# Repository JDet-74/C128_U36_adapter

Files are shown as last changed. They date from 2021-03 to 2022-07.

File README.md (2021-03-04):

# C128_U36_adapter
A new design of the megabit adapter for U36 in the C128
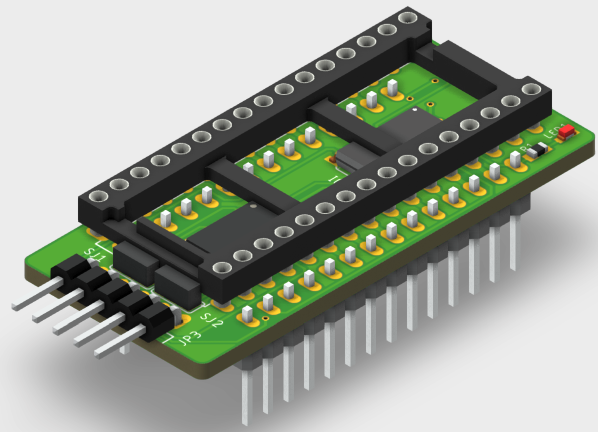
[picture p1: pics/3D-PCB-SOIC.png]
3D PCB SOIC Version
 <br>
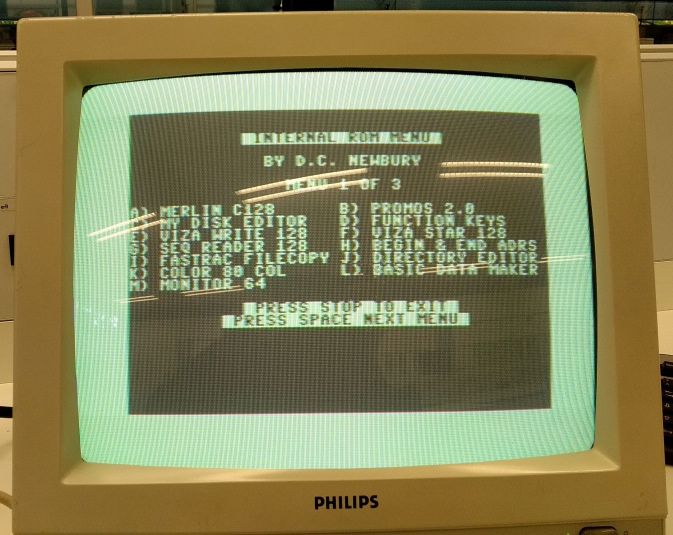
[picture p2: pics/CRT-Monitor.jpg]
CRT Monitor
 <br>

# The story began ...
I tried to recreate the original Megabit adapter for the U36 socket in the C128.
The information to this project I found on cmb8bit.com. You can find the PDFs and the ROM binary file in the <strong>cmb8bit.com</strong> directory.

<ul>
    <li> <a href="./cbm8bit.com/Megabit_internal_rom_manual.pdf"> Megabit internal ROM manual</a> </li>
    <li> <a href="./cbm8bit.com/MegaBit-faq-howtoo.pdf"> Megabit FAQ HowTo</a> </li>
    <li> <a href="./cbm8bit.com/megabit-help.BIN"> megabit-help.bin</a> </li>
</ul>

# The issue was ...
I designed a PCB with the information of the PDFs and tested the soldered PCB. <br>
Unfortunately it does not work :( <br>
Thankfully a guy (Kinzi) from the great Forum64 helped me out by troubleshooting. <br>
I scoped the signals and figured out, that the transistor I used was too slow to trigger the D-FF. <br>
After that I tried logic gates - but this does not work either.
I figured out that there is a GLITCH on Pin12 of U3 <br>
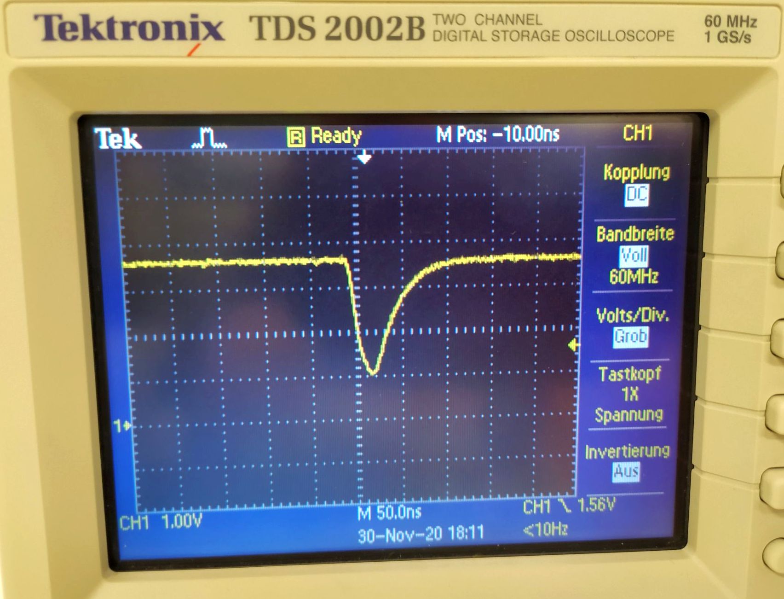
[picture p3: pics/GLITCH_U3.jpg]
GLITCH on U3 pin 12
 <br>
The GLITCH triggered always the D-FF and so it does not work :( what a bummer ;(

# The solution was ...
Kinzi mentioned that the /CS signal from pin12 of U3 has to be synchronized with the 1MHz clock of the C128. <br>
So I poked around with this variation and that was the success. <br>
The solution is to use two 74HCT173 D-FF and one 74HCT14 INV - so the /CS signal from pin 12 of U3 gets synchronized with the system clock
and addresses the ROM. BINGO <br>
<p>Take a look into the <a href="C128_U36_adapter_MANUAL.pdf"> C128 U36 adapter manual</a> or into the 
    <a href="Schematic_U36_adapter.pdf"> SCHEMATIC </a>for further information.</p>

# In the C128D-CR ...
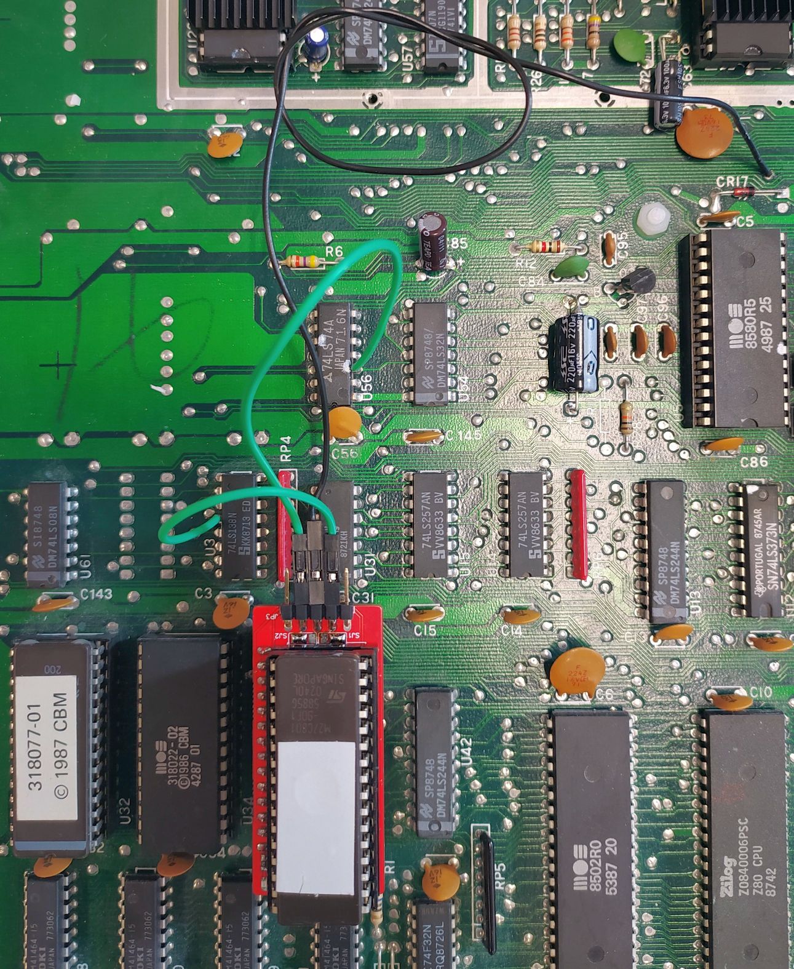
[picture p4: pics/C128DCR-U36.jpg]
C128D-CR with the Megabit ROM
 <br>

# In the C128 ...
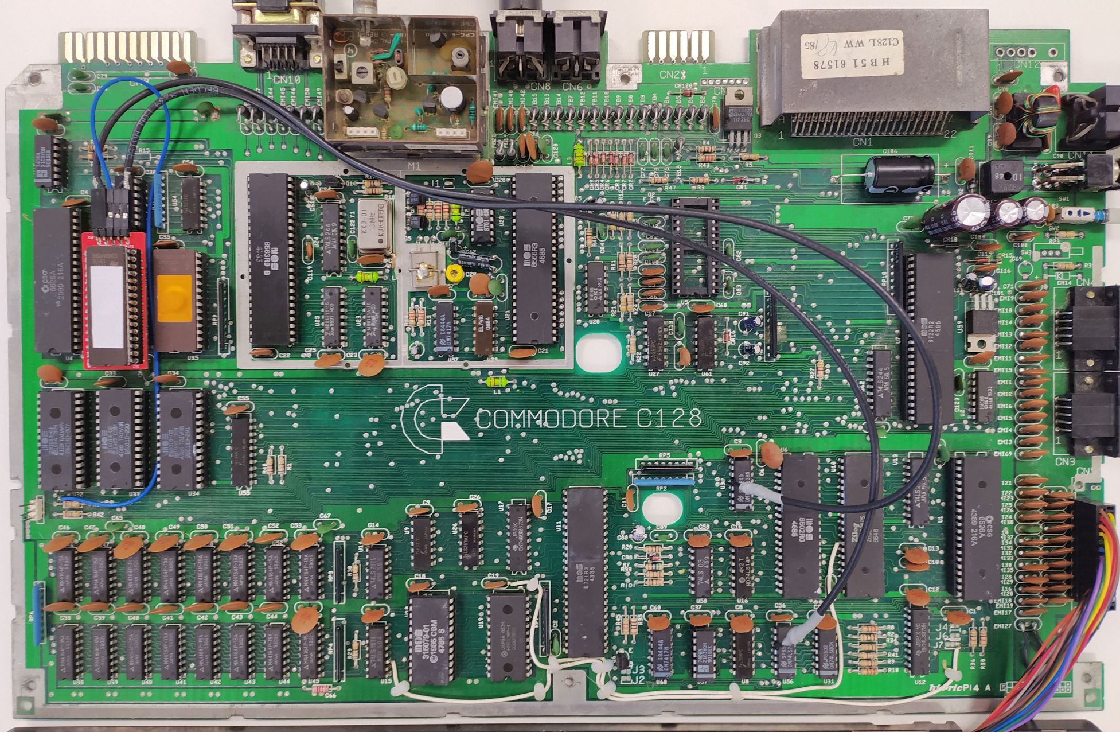
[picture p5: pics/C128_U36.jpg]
C128 with the Megabit ROM
 <br>

# Fabrication files
You can find a panelized GERBER file version and a single file version. <br>
The panelized version should work for the most PCB manufacturer.
I ordered by JLCPCB.

# Contact
For any questions (technical / experience), please use the issue tracking system of github.

Greetz 

JDet

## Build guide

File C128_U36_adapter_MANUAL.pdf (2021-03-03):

# C128_U36_adapter

https://github.com/JDet-74/C128_U36_adapter.git

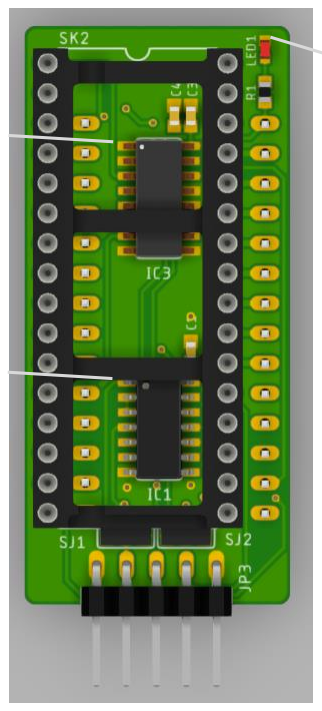
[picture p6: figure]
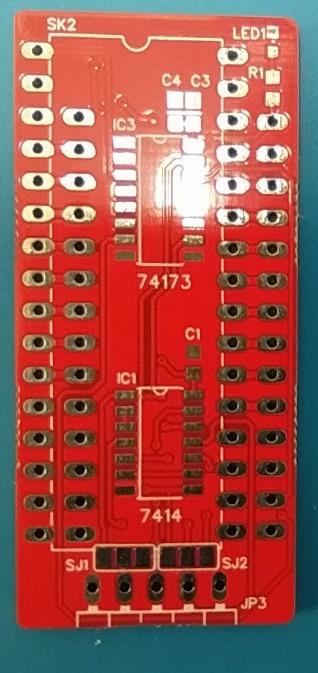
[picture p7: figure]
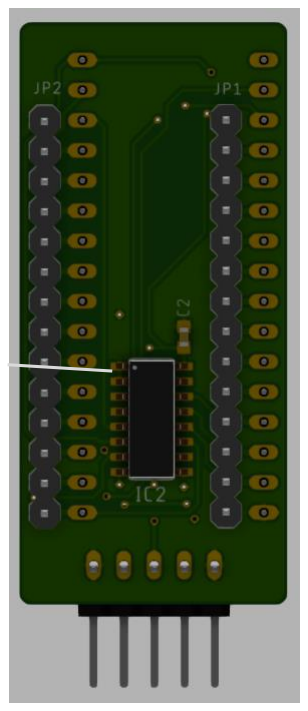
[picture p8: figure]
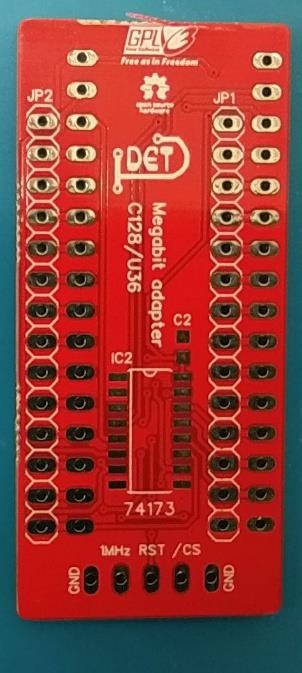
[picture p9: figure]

C128_U36_adapter | Seite: 1 von 3
Bestückungs-Info | Assembling information
TOP Side:

BOTTOM Side:

BOM:

SK2: DIP-32 Socket (2,54 x 15,24mm)
JP1 & JP2: 1x14 pin header (2,54mm) – JP3: 1x5 pin header (2,54mm)
IC1: 74HCT14 (INVERTER) SO14 – IC2 & IC3: 74HCT173 (D-FF) SO14
C1 – C4: 100nF (ceramic capacitor) 0603 – R1: 1,5k (resistor) 0603 – LED1: SMD LED 0603

GND (-)
Kathode / cathode
Pin1

Pin1

Pin1

/CS through 4 inverter gates to the D-FFs

C128D-CR | C128D-CR

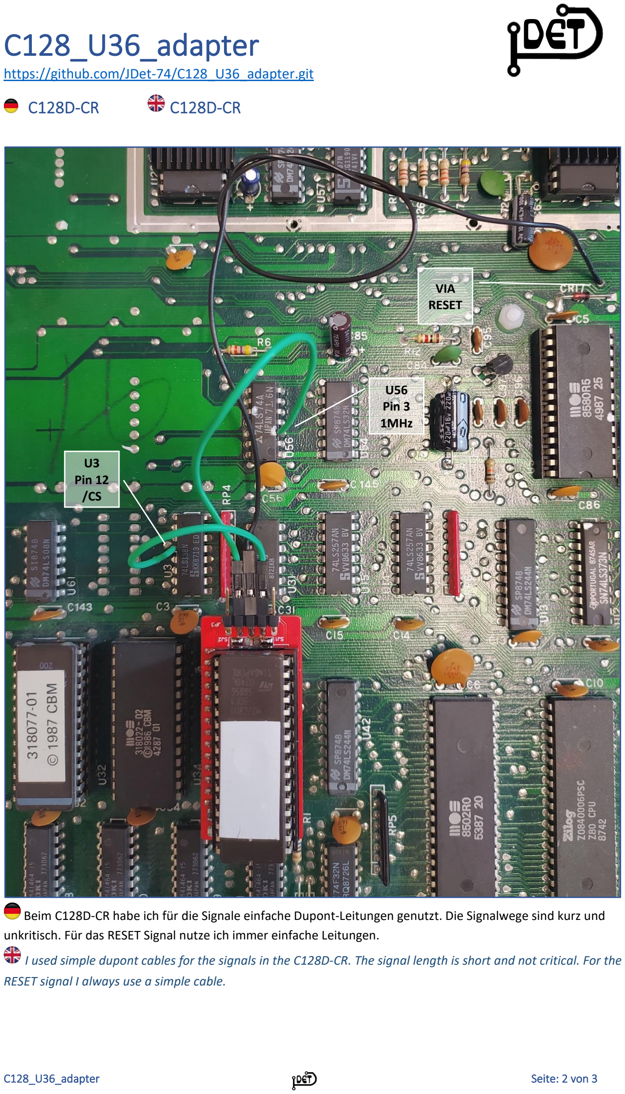
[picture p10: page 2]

https://github.com/JDet-74/C128_U36_adapter.git

Beim C128D-CR habe ich für die Signale einfache Dupont-Leitungen genutzt. Die Signalwege sind kurz und unkritisch. Für das RESET Signal nutze ich immer einfache Leitungen.

I used simple dupont cables for the signals in the C128D-CR. The signal length is short and not critical. For the RESET signal I always use a simple cable.

U3
Pin 12
/CS

U56
Pin 3
1MHz

VIA
RESET https://github.com/JDet-74/C128_U36_adapter.git
C128 | C128

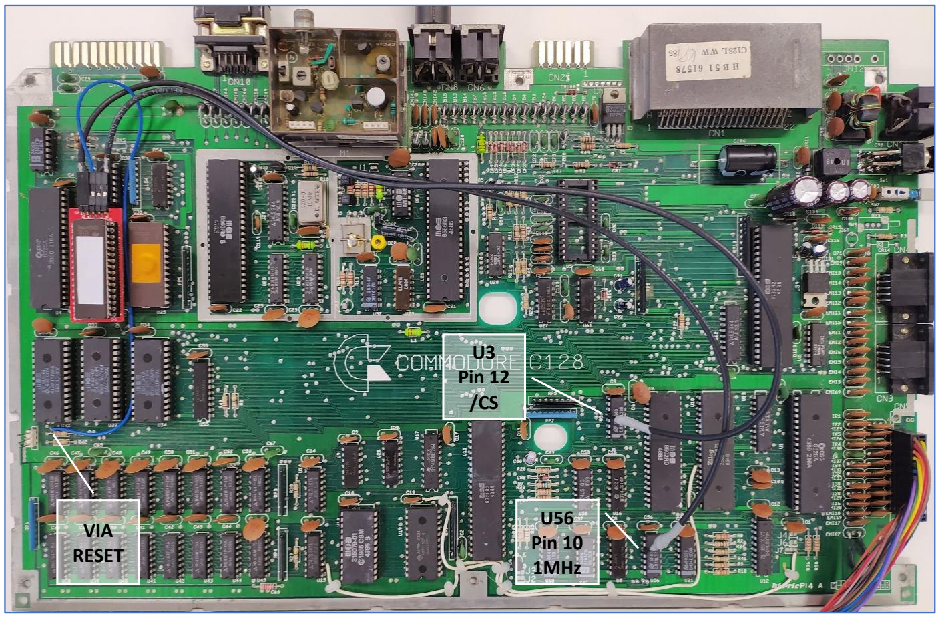
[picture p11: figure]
U56 Pin 10 1MHz; U3 Pin 12 /CS; VIA RESET

Beim C128 habe ich für die Signale geschirmte Koaxial-Leitung benutzt. Die Signalwege sind lange und somit eventuell kritisch für elektromagnetische Einstreuungen. Für das RESET Signal nutze ich immer einfache Leitungen. Die geschirmten Leitungen habe ich selbst hergestellt.

I used screened coax cables for the signals in the C128. The signal length is long and there may be some electromagnetic disturbance. For the RESET signal I always use a simple cable. I built the screened cables by myself.

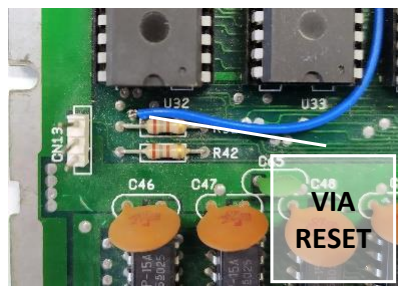
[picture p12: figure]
VIA RESET

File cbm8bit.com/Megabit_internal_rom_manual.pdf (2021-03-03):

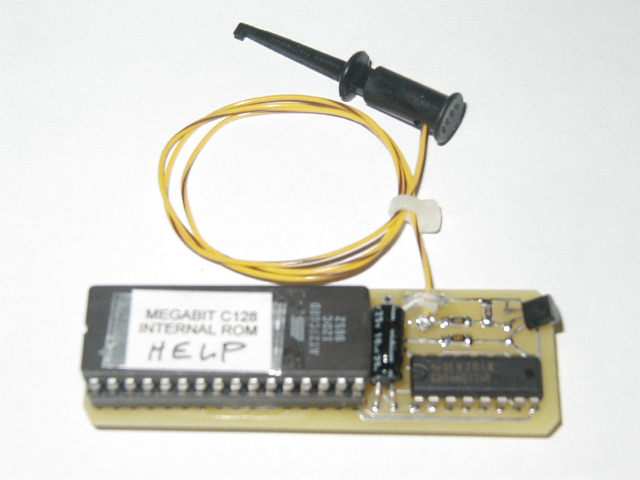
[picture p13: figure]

Page 1

# MEGABIT INTERNAL ROM ADAPTER

## BY D. C. NEWBURY

## FOR THE COMMODORE C128 AND 128D COMPUTERS

Page 2

Page 3

TABLE OF CONTENTS

PAGE
INTRODUCTION ----------------------------------------------------------- 5

INSTALLATION ------------------------------------------------------------ 6 C128 ------------------------------------------------------------------ 6 128D ------------------------------------------------------------------ 7 FIGURES 1 & 2 ----------------------------------------------------- 8 FIGURE 3 ------------------------------------------------------------ 9

INTERNAL ROM PROGRAMS ----------------------------------------- 10 MENU 1 -------------------------------------------------------------- 10 MENU 2 -------------------------------------------------------------- 11 MENU 3 -------------------------------------------------------------- 12 MERLIN 128 -------------------------------------------------------- 13 PROMOS 2.0 ------------------------------------------------------- 13 VIZAWRITE 128 --------------------------------------------------- 13 VIZASTAR 128 ----------------------------------------------------- 13 FASTRAC FILECOPY -------------------------------------------- 14 DIRECTORY EDITOR -------------------------------------------- 14 MONITOR 64 ------------------------------------------------------- 14 MAV FILE COPY -------------------------------------------------- 14 MAV TRACK EDITOR -------------------------------------------- 14 SGL 41 DATA COPY --------------------------------------------- 14 DUL 41 DATA COPY --------------------------------------------- 14 SINGLE NYBBLER ------------------------------------------------ 15 DUAL NYBBLER --------------------------------------------------- 15 SGL 81 DATA COPY --------------------------------------------- 15 MAV FILE TRACER ----------------------------------------------- 15 MAV TRK&SEC EDIT --------------------------------------------- 15 64K VDC TEST ----------------------------------------------------- 15 REU TEST ----------------------------------------------------------- 15 ZED 128 -------------------------------------------------------------- 16 BASIC MERGE + --------------------------------------------------- 16

Page 4

INTERNAL ROM FIRMWARE ------------------------------------------- 17 MY DISK EDITOR -------------------------------------------------- 17 FUNCTION KEYS -------------------------------------------------- 21 SEQ READER 128 ------------------------------------------------- 21 BEGIN & END ADRS ---------------------------------------------- 22 COLOR 80 COL ----------------------------------------------------- 22 BASIC DATA MAKER --------------------------------------------- 24 BASIC 8 --------------------------------------------------------------- 24 SERVANT v4.84 ---------------------------------------------------- 24 KeyDOS --------------------------------------------------------------- 24

Page 5

INTRODUCTION

The Megabit 128 Internal ROM Adapter is an adapter that will allow the use of high capacity EPROMs such as 27010 (1 Meg.), 27020 (2 Meg.), 27040 (4 Meg.) and 27080 (8 Meg.).

It’s very easy to install, the only soldering involved will be to de-solder the shield from the C128 Printed Circuit Board (PCB). Then plug the adapter into the empty Internal ROM socket on the left side of the PCB and install the mini clip. That’s it.

There has been an addition to the PC Board. A direction diode and a place on the board to add a 24-26 AWG insulated wire (=> 12”). On the opposite end you can tack solder it to any one of the RESET lines in the computer or if you have a mini-clip in your junk box put it on the end of the wire.

There are a few programs in the ROM that require you to turn the computer off and then back on. With the wire connected to a reset line, you will be able to use the reset button instead of turning the computer off.

The remainder of this manual will cover installation and how to use the software that came with the adapter. If there is an interest by some to make their own adapter and program their own EPROM, then I will supply the schematics, layout and parts list. Also some do’s and don’ts and source code (menu and program loaders).

Page 6

INSTALLATION

C128

1. Remove all cables connected to the C128, especially the power cable. If you have had your C128 apart before, then you can skip steps 2 thru 4.
2. Turn the C128 over, keyboard down and remove six screws (2 at the top, one in the middle and three along the bottom).
3. Turn the C128 over, keyboard up and pop the cover off. Unplug the power LED, the keyboard connector and remove the ground wire. Set the cover/keyboard aside.
4. Remove the screws around the outside edge holding the shield in place and one screw in the upper left side. There may be one or two places where the shield is tack soldered to the ground plane of the PCB. De-solder the shield and remove the shield from the PCB.
5. Notice the empty 28-pin IC socket at the upper left side of the PCB. There may be 2 or 3 disk caps standing up that will be in your way when you install the adapter. Push them over flat against the PC Board. Install the adapter in the socket. Install the mini clip to pin 12 of IC U3. See Figures 1 and 2.
6. If you want to re-install the shield, you will have to enlarge the opening around the Internal ROM socket area.

I have used my C128 for years without a shield and have had no problems with overheating or RFI interference. But that is up to you.

Install the shield; make sure the shield does not touch the adapter PCB. Install the screws and re-solder the shield to the ground plane. If you do not want to install the shield, then screw the PCB to the bottom cover.

7. Re-install the cover/keyboard. Connect the ground wire, the keyboard connector and the power LED. Snap the cover in place and turn the C128 over and install the six screws.
8. Install all of the cables and turn the system on. On the label of the EPROM you will find the name of the function key that has been programmed to activate the Internal ROM Menu, press the key and it will come up on the screen.

Page 7

NOTE: If you have a JiffyDOS adapter installed, remove it first then install the Internal ROM Adapter. Then re-install your JiffyDOS adapter. If the edge of the JiffyDOS adapter touches the ROM leads of the Internal ROM Adapter, put a small piece of insulating tape between them.

128D

1. Remove all cables connected to the 128D, especially the power cable. If you have had your 128D apart before, then you can skip step 2.
2. To remove the metal cover on the 128D, you will have to remove five screws, three on the back and two by the plastic bezel at the front of the computer. Once the screws have been removed, push the cover toward the rear of the computer. It will slide back about half an inch, then lift the cover straight up and set it aside. Sometimes the cover will stick and not slide easily. Take a flat blade screwdriver and carefully pry it loose at the rear of the computer.
3. Notice the empty 28-pin IC socket at the left side of the PCB, in front of the power supply. There may be 2 or 3 disk caps standing up that will be in your way when you install the adapter. Push them over flat against the PC Board. Place the rear of the adapter under the power supply, line up the pins with the IC socket and push it in place. Now install the mini clip to pin 12 of IC U3. See Figures 2 and 3.
4. Re-install the cover and five screws. Install the cables and turn the system on. On the label of the EPROM you will find the name of the function key that has been programmed to activate the Internal ROM Menu, press the key and it will come up on the screen.

NOTE:

If the Menu does not show up, then turn off the computer, go back to step 1. After you have removed the cover and shield, check the mini clip and make sure it’s connected to U3 pin 12. Make sure the adapter is plugged in properly, the pins on the adapter line up with the sockets of the IC socket. Put the computer back together and try again.

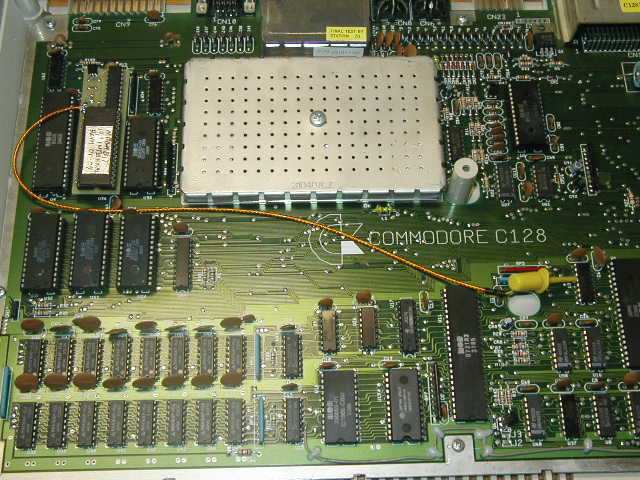
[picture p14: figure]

Page 8

FIGURE 1: C128 INSTALLATION

FIGURE 2: U3 CONNECTION

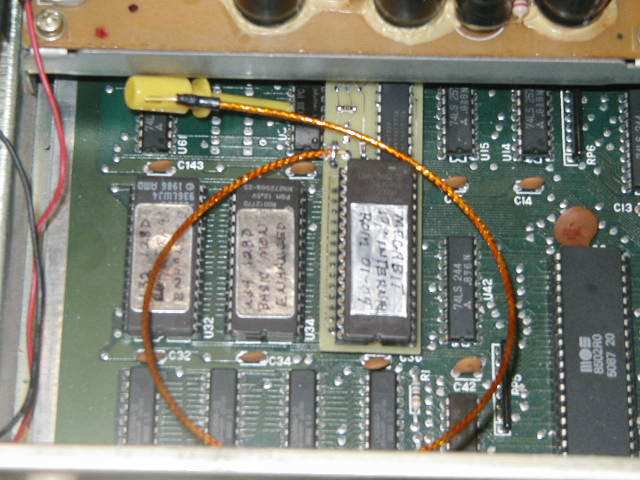
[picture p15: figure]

Page 9

FIGURE 3: 128D INSTALLATION

Page 10

BY D. C. NEWBURY
MENU 1 OF 3
A) MERLIN C128 | B) PROMOS 2.0
C) MY DISK EDITOR | D) FUNCTION KEYS
E) VIZA WRITE 128 | F) VIZA STAR 128
G) SEQ READER 128 | H) BEGIN & END ADRS
I) FASTRAC FILECOPY J) DIRECTORY EDITOR
K) COLOR 80 COL L) BASIC DATA MAKER
M) MONITOR 64

INTERNAL ROM PROGRAMS

Most of the Programs in this ROM are the software/firmware that I use in my C128 and 128D. Below are pictures of the three menus.

MENU 1

MEGABIT INTERNAL ROM MENU

PRESS STOP TO EXIT
PRESS SPACE NEXT MENU

Page 11

BY D. C. NEWBURY

MENU 2 OF 3

N) ZED 128 | O) BASIC MERGE +
P) MAV FILE COPY | Q) MAV TRACK EDITOR
R) SGL 41 DATA COPY S) DUL 41 DATA COPY
T) SINGLE NYBBLER U) DUAL NYBBLER
V) SGL 81 DATA COPY W) MAV FILE TRACER
X) MAV TRK&SEC EDIT Y) 64K VDC RAM TEST
Z) REU TEST

PRESS STOP TO EXIT
PRESS SPACE NEXT MENU

MENU 2

MEGABIT INTERNAL ROM MENU

Page 12

BY D. C. NEWBURY

MENU 3 OF 3

£) BASIC 8 | ↑) SERVANT
←) KEY DOS

MENU 3

The menu is simple to use, select the letter in front of the program you want to use. Press the space bar to move from menu to menu. Press the stop key to reset the computer and return to basic. Any letter can be selected while in any of the three menus. Below is a list of software and a brief description.

MEGABIT INTERNAL ROM MENU

PRESS STOP TO EXIT
PRESS SPACE NEXT MENU

Page 13

A) MERLIN C128

Merlin C128 Version 1.0 is a macro assembler system for the Commodore C128/128D. The program runs in 80 column mode only. The manual is included on CD in PDF format.
The program has been modified, when first loaded THE SORCEROR and SORCEROR LABELS are loaded also. To access SORCEROR, when the program is first started, press ‘B’. It will ask if you want labels Y/N?. Then it will go back to the opening screen. Now follow the instructions in the manual, Page 114, start with step 2 (except loading SORCEROR).
B) PROMOS 2.0

Promos 2.0 is software used to read/program EPROMs on the Promenade C1 EPROM Programmer. The program runs in 40 or 80 column mode. The manual is included on CD. You’ll find it attached to the end of the EPROM Programmers Handbook in PDF format.

E) VIZA WRITE 128

Vizawrite 128 is a Word Processor used on the Commodore C128/128D. The program runs in 80 column mode only. The manual is included on CD in PDF format. Copies of the program disks are included on CD in D64 format. To exit the program you will have to turn off the computer.

E) VIZA STAR 128

Vizastar 128 is a Spreadsheet and Database used on the Commodore C128/128D. The program runs in 80 column mode only. The manual is included on CD in PDF format. Copies of the program disks are included on CD in D64 format. To exit the program you will have to turn off the computer.

Page 14

I) FASTRAC FILECOPY

This File Copier is from Fastrac 128 used on the Commodore C128/128D. The program runs in 40 or 80 column mode. The manual is included on CD in PDF format.

J) DIRECTORY EDITOR

This Directory Editor is from Fastrac 128 used on the Commodore C128/128D. The program runs in 40 or 80 column mode. The manual is included on CD in PDF format.

M) MONITOR 64

Monitor64 is SUPERMON V1.2 by Jim Butterfield that I modified back in the day (1980’s). It runs in C64 mode only but allows the use of the C128/128D keypad and cursor keys. It also has a print mode that will send the output to device 4. Documentation for the monitor is on CD, D64 file name is MIRA.D64

P) MAV FILE COPY

This File Copier is from MAVERICK V5.04. It runs in C64 mode only. The manual is included on CD in PDF format.

Q) MAV TRACK EDITOR

This Track Editor is from MAVERICK V5.04. It runs in C64 mode only. The manual is included on CD in PDF format.

R) SGL 41 DATA COPY

This 1541 Data Copier is from MAVERICK V5.04. It runs in C64 mode only. The manual is included on CD in PDF format.

S) DUL 41 DATA COPY

This Dual 1541 Data Copier is from MAVERICK V5.04. It runs in C64 mode only. The manual is included on CD in PDF format.

Page 15

T) SINGLE NYBBLER

This Single 1541 Nybbler is from MAVERICK V5.04. It runs in C64 mode only. The manual is included on CD in PDF format.

U) DUAL NYBBLER

This Dual 1541 Nybbler is from MAVERICK V5.04. It runs in C64 mode only. The manual is included on CD in PDF format.

V) SGL 81 DATA COPY

This Single 1581 Data Copier is from MAVERICK V5.04. It runs in C64 mode only. The manual is included on CD in PDF format.

W) MAV FILE TRACER

This File Tracer is from MAVERICK V5.04. It runs in C64 mode only. The manual is included on CD in PDF format.

X) MAV TRK&SEC EDIT

This Track & Sector Editor is from MAVERICK V5.04. It runs in C64 mode only. The manual is included on CD in PDF format.

Y) 64k VDC TEST

This 64K VDC Test Routine is from MAVERICK V5.04. It runs in C64 mode only. The manual is included on CD in PDF format.

Z) REU TEST

This Ram Expansion Unit Test Routine is from MAVERICK V5.04. It runs in C64 mode only. The manual is included on CD in PDF format.

Page 16

N) ZED 128

This program is a text editor program (version 0.77.00) for the Commodore 128. It runs in 80-column mode only. Instructions for the program is on CD in pdf format.

O) BASIC MERGE +

This program will merge two basic programs, but it will renumber the line numbers and update all the GOTO’s and GOSUB’s. With this merge routine, you will NOT have to make sure the program that you merge has a higher line number. When you select BASIC MERGE +, the program will be loaded in memory at $0C00.

To use the program, select BASIC MERGE + from the menu. Then DLOAD your first basic program, then type ‘SYS3072:DLOAD”second program’ and press return. Press F7 and both programs will be listed.

One thing about merging programs, watch your variables.

The following programs run in ROM (function ROM). Once selected, you cannot use the other programs in the Function ROM.

Page 17

INTERNAL ROM FIRMWARE

C) MY DISK EDITOR

This Disk Editor was written in the 1980’s when I was learning to program in ML. It will run in 40 or 80 column mode and will read/write 1541 or 1571 disks in drive 8 only. I could not afford a 1581 back then. If you need to read/write a 1581 disk then use the Maverick Track & Sector Editor.

To start the program, put a disk in the drive. The program will not do anything fancy while reading a track/sector, so if there is a bad track or sector ‘do not trust the data on the display’.

When the program starts it will initialize the disk, fill the buffer with 0’s. The opening display will look like the picture on the next page. Notice the 3 extra lines at the bottom of the screen; I call it the status line area. It shows what each function key is programmed for and displays all of the commands.

Bugs I never fixed: Where it says ‘DRIVE 1571’, I was going to write a routine that would recognize the drive (1541/1571) and display it. Also a routine that would change the drive number (8,9,10,11). It has been over 20 years now, so I will probably never get it done.

Page 18

BY D. C. NEWBURY

DRIVE 1571 TRACK $00 #00 SECTOR $00 #00

00 00 00 00 00 00 00 00 00 00 00 00 00 00 00 00 00 00 00 00 00 00 00 00 00 00 00 00 00 00 00 00 00 00 00 00 00 00 00 00 00 00 00 00 00 00 00 00 00 00 00 00 00 00 00 00 00 00 00 00 00 00 00 00 00 00 00 00 00 00 00 00 00 00 00 00 00 00 00 00 00 00 00 00 00 00 00 00 00 00 00 00 00 00 00 00 00 00 00 00 00 00 00 00 00 00 00 00 00 00 00 00 00 00 00 00 00 00 00 00 00 00 00 00 00 00 00 00 00 00 00 00 00 00 00 00 00 00 00 00 00 00 00 00 00 00 00 00 00 00 00 00 00 00 00 00 00 00 00 00 00 00 00 00 00 00 00 00 00 00 00 00 00 00 00 00 00 00 00 00 00 00 00 00 00 00 00 00 00 00 00 00 00 00 00 00 00 00 00 00 00 00 00 00 00 00 00 00 00 00 00 00 00 00 00 00 00 00 00 00 00 00 00 00 00 00 00 00 00 00 00 00 00 00 00 00 00 00 00 00 00 00 00 00 00 00 00 00 00 00 00 00 00 00 00 00

■

STARTUP DISPLAY

The ‘<’ in the above status line area represents a carriage return. In the actual display on an 80 column monitor, it will be a back arrow.

The TRACK number and SECTOR number is displayed above the buffer area in hex and decimal.

The command line is located below the buffer display on the left side of the screen. The flashing cursor will always return to that location after completing a command.

C128 DISK EDITOR

H 00 01 02 03 04 05 06 07 08 09 0A 0B 0C 0D 0E 0F >00
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
F1=R12 01< F3=+< F5=-< F7=C< F9=T< R=READS T&S W=WRITES T&S I=READS BAM F2=R01 00< F4=J+< F6=J-< F8=T< F10=P< C=HEX/ASCII/SCN P=PRT SCN X=EXIT PGRM M=ENTER MON T=TGL CHAR S=NEW SCN +=NEXT SEC -=LAST SEC J+/J- =JMP PGRM+/-

Page 19

List of Commands and Definitions

R – | Reads the track and sector specified: R12 01 or R#18 #1 will read track 18 ($12) sector 1 ($01). The program assumes a hexadecimal number, for a decimal number, you will have to put a sharp sign (#) in front of the number.
W – | Writes the track and sector specified: W12 01 or W#18 #1 will write track 18 ($12) sector 1 ($01). The program assumes a hexadecimal number, for a decimal number, you will have to put a sharp sign (#) in front of the number.
I - | This command will initialize the disk in drive 8 (read the BAM). Any time you change disks without restarting the program, you should initialize the new disk. If you read a track and sector from one disk and want to write it to another disk, then initialize the other disk before you write to it.
C - | This command will toggle the characters in the buffer display from hex to ascii to screen code and back to hex. It will not change the data in the buffer.
P - | This command will send the screen to a Commodore compatible printer setup as device 4.
X - | This command will exit the program and reset the computer.
M - | This command will jump to the 128 monitor. It can be used to change data in the buffer, disassemble code in the buffer or transfer data in or out of the buffer area. The buffer area is located at $0B00 to $0BFF. By the way, don’t change any data at $0C00 to $0FFF. The program uses this area to store the tracks and sectors when using the J+ and J- commands. To re-enter the program, press ‘X’ then the RETURN key.
T - | This command will toggle the character set from uppercase to lowercase and back again.
S - | This command will re-fresh the screen. The cursor can be moved around the screen anywhere accept the status line area. So if the display gets accidentally messed up, just move the cursor to the command line, press ‘S’ then the RETURN key.
+ - | This command will single step to the next sector. If you have just read track 12 sector 02, then it will read track 12 sector 03. If you keep going to the last sector, then it will increment to track 13 sector 00.

Page 20

- - This command will single step back one sector. If you have just read track 12 sector 02, then it will read track 12 sector 01. If you keep going to sector 00, then it will increment to track 11 sector 14.

J+ - This command will jump to the next track/sector of a file that is stored on the disk. The first 2 bytes in each sector points to the next track and sector (254 bytes) of the file you are jumping through. When you reach the end of the file, the second byte in the sector will tell the drive how many bytes in this sector belongs to the file (00-FF).

J- - This command will jump backwards from the track and sector that you J+. When you J+, the track and sector is stored in a separate buffer ($0C00 to $0FFF). J- will take you back to where you came from.

FUNCTION KEY DEFINITIONS

F1 = | R12 01 | , reads track 18 sector 1 which is the first sector of the directory.
Press F7 and the display will change to ascii.
F2 = | R01 00 | , reads track 1 sector 0 which is where the autoboot routine is stored.
F3 = | + , will jump forward one sector.
F4 = | J+ | , will jump to the track and sector specified by the first two bytes in the
buffer.
F5 = | - | , will jump backward one sector.
F6 = | J- | , will jump backward to last J+ track and sector.
F7 = | C | , will change the display characters from hex to ascii to screen code and
back again.
F8 = | I | , will initialize the disk in the drive.
F9 = | T | , will toggle the character set from uppercase to lowercase and back again.
F9 is actually the shift/runstop keys.

F10 = P , will send the screen to a printer, device 4. F10 is actually the help key.

In the status display, the back arrow represents a carriage return (CR).

Page 21

To edit data in the buffer area (hex only), move the cursor to the byte or bytes you want to change. Make sure you maintain the same format, byte-space-byte, etc. Change one line at a time. Enter your change and hit the carriage return and the change will be entered in the buffer at $0B00 - $0BFF. After you have made your changes, write the sector back to the disk.

D) FUNCTION KEYS

The function key program will write two extra lines on the monitor display and scan the function key area at $1000 in RAM. It will then display in the status line area how you have your function keys programmed, including the shift/run keys and the help key.

A carriage return will display as a back arrow, the escape key will display as an up arrow and the tab key will display as a blank space.

FUNCTION KEYS will not work in 40 column mode. To clear the function key display, push the reset button.

G) SEQ READER 128

This program is a sequential text file reader. It will run fine as long as there is not a lot of fancy formatting in the file. It’s easy and quick to use and will run in 40 or 80 column mode.

When the program is started, you’ll see the familiar status line area that tells you what function key to use. Put a disk in drive 8, press F3 and the directory will be displayed on the screen. To load a file, move the cursor up the left side of the directory listing. Align the cursor with the file you want to look at, press F1 and the file will fill the screen. If the file is longer than 21 lines, then it will pause and give you an option to continue by pressing the space bar, print the screen by pressing ‘P’ or quit by pressing ‘Q’. When you have reached the end of the file, it will pause again, let you know that you have reach the end and allow you to print the screen or quit.

If you want to print a complete file, then press F5 to activate print mode. Press F3, list the directory, line up the cursor and press F1. The file will go to the printer and echo to the screen.

Press F7 to toggle the character set, uppercase, lowercase.

Press ‘X’ to exit the program and reset the computer.

Page 22

H) BEGIN & END ADRS

This program will give you the beginning address (loading address), the ending address and the total number of bytes of a selected PRG file.

The display has the familiar status line area with the function key definitions. F1 will check a file, F3 will read the directory, F5 will send the data on the screen to a printer (device 4) and F7 will exit the program and reset the computer.

To check a file on disk, first list the directory (F3), then move the cursor up the left side of the listing and align the cursor with the file you want to check. Press F1 and the program will take the information from the serial bus until the end of the file is reached. The file is not loaded into memory; the only memory used is to store the loading address, total number of bytes and the end address of the file

The display will list the beginning address, the ending address, the number of bytes in hexadecimal and decimal.

K) COLOR 80 COL

This program was written to allow you to make your own color adjustments to your monitor. To make the adjustments, you need a pattern that will stay still while making adjustments.

There are three different patterns to this program, one pattern with Black dots and a white background, one pattern with red, green and blue Color bands and one pattern with one line each of the sixteen colors repeated to fill the whole screen. From each screen, press the space bar to return to the menu.

Let’s talk in detail about each pattern, starting with "A" black dots. This pattern is used to make color convergence adjustments on your monitor screen. If your monitor is adjusted properly you should see all black dots and a white background. If the white background is not white, then try adjusting the color, tint and contrast controls. The black dots are a little harder to explain. If you look closely at the edges of the dots, you may see color spilling over the edge. This can happen anywhere on the screen, but mostly you'll see it happening at the edges of the screen. If your convergence is not adjusted properly then you'll see color at all of the black dots.

With all black dots displayed, shift the screen left or right to center the black dot display, by pressing ‘L’ for left ‘R’ for right.

Page 23

Before we go any further with this, I want to caution you about making convergence adjustments. If you feel your monitor needs adjusting, and you have never done this before, take your monitor to a service facility or a friend that you have confidence in. The reason is because the back cover will have to be removed, exposing yourself to very hazardous voltages. Also the adjustments are numerous and it takes some experience to make the necessary adjustments.

If you make the adjustments yourself, don't get discouraged, it's not easy and it's very time consuming, especially without instructions. Don't expect to get it 100% perfect. 90% to 95% is more likely. You'll have to compromise a little, but compromise at the edges of the screen not the middle. Good luck!

The next screen "B" red green blue, is used to make vertical height and vertical linearity adjustments. There should be three color bands on the screen and each color band should be the same width. If not then your vert. Linearity needs to be adjusted. On some monitors the adjustments can be made from the outside of the cabinet or with a screwdriver through an access hole in the cabinet and are usually marked. Others, the cover will have to be removed to get access to the controls. In either case, once you’re ready to make the adjustments, select the proper screen by pressing "B".

First, adjust the vert. Height control until the raster begins to pull away from the bottom or the top of the screen, usually by turning the control in the counter-clockwise direction. Then turn the control in the opposite direction until the raster just fills the screen. Measure the width of the color bands, if they’re equal then you don't have to make any more adjustments. If not, then adjust the Vert. Linearity control to get them as close as possible. The raster may pull away again at the top or bottom of the screen, but in any case, adjust the vert. height control again just as you did before. You may have to make both adjustments several times to get it right. When you have it adjusted properly the color bands will be the same width and the raster will just fill the screen.

The third screen, "C" all colors, is used for making adjustments of the brightness, contrast, color and tint controls. No explanation here is necessary. Everyone will have their own preference.

Page 24

L) BASIC DATA MAKER

This program will make a data listing of any ML program on disk or from memory in any bank (0-15). When BASIC DATA MAKER is started you will see the familiar status line area that defines the function keys.

F1 - is used to select a file from a disk in drive 8.

F3 - will list the directory of the disk in drive 8. With the directory listed on screen, move the cursor up the left side of the screen and line it up with the program you want to convert. Press F1, the program will be loaded, converted and the program will exit and go to basic. Press F7 and your data listing will list on the screen. You can ‘DSAVE’ the data listing at this point to merge with another basic program.

F5 - will make a data listing from anywhere in RAM 0/1. When you press F5, ‘R,’ will show up on the screen. You have to enter a beginning address, ending address and bank number, in hex only.
The proper syntax is: R,0C00,0D24,0 or R,0C00,0D24,1. The first example will make a data listing from $0C00 to $0D24 from RAM 0, the second example will come from RAM 1.

F7 - will exit the program and reset the computer.

£) BASIC 8

This program is an extension to the basic 7 that comes with the C128/128D. Documentation is on the CD in pdf format, also a BASIC 8 disk in D64 format. To exit the program, you will have to power down.

) SERVANT v4.84

This program has utilities for the C128. Documentation is on the CD in pdf format. To exit the program, you will have to power down.

) KeyDOS

This program has utilities for the C128. Documentation is on the CD in pdf format, also a KeyDOS utility disk in D64 format. To exit the program, you will have to power down.

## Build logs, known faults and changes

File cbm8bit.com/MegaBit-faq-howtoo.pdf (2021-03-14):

### 1. Introduction

### 2. How it works

### 3. Auto start and program Function Keys

### 4. Menus

### 5. Loaders for different sized programs

### 6. Loaders for C64 programs

### 7. Appendix 1 – Source Code listings

### 8. Appendix 2 – Parts Lists and Schematics

### INTRODUCTION

### I started playing with the Internal ROM socket in the C128 back in the late 1980’s. At first I used 32K (27256) EPROMs, but ran out of room quickly. I decided to try to find

something that had more room for programs.

### Intel was making an EPROM (27513) that they called a Paged EPROM. It had 4 – 16K pages of ROM, equivalent to a 64K (27512) EPROM. I used the I/O at the Expansion Port to

select a page on the EPROM (1,2,3 or 4). Put the page number on the Data Bus and write to the

### I/O address ($DE00). Whatever page you select, 16K of ROM will show up at $8000 – $9FFF

and again at $A000 – $BFFF. It was OK for awhile, but I still did not have enough room for the programs I used most of the time.

Then Intel came out with an 8 paged EPROM (27011) 8 – 16K pages (1 MEG) of ROM. I was able to put most of my programs and a couple of large programs that I use, Merlin 128 and

### Word Writer, in the ROM. Intel talked about making a 2 MEG Paged EPROM, but it never showed up. Their next 2 MEG EPROM was the 27020, 32-pin package. In order to use the 32-

pin package, I would have to make an adapter with controlling circuitry. I didn’t want to fool with it at the time, I thought 1 MEG of ROM would be enough.

### The 27513 and the 27011 EPROMs are 28-pin packages and were easy to install. The page select pin is pin 27. After the ROM was programmed, bend pin 27 up enough so the pin

would not go into the socket when installed in the C128, tack solder a lead to pin 27 with a clip on the other end and clip it to the I/O on the Expansion Port. That’s it, no adapter and easy to install. Later, I started using a socket with pin 27 removed. It was easier to erase and reprogram the EPROM.

### I programmed several 27010 EPROMs for friends in our computer club and I gave a demonstration at the Kansas City, MO computer club. After awhile I moved away from

Commodore and concentrated on my job and preparing for retirement. I retired 5 years ago and started playing with the C128 again.

### I decided to play around with the large capacity EPROMs, 27010 (1 MEG), 27020 (2

MEG), 27040 (4 MEG) and 27080 (8 MEG).

### First I made a cartridge board for the C64 that would accommodate any one of the four

high capacity EPROMs.

The C64 will only see 8k or 16k of ROM, so I set it up to use 16k, from $8000 to $BFFF.

### So with the 1 meg EPROM you will have 8 – 16k sections of PROM available. From this point

forward the word section(s) will be referred to Page(s). With a 2 MEG EPROM there will be 16

### – 16k Pages of PROM, with a 4 MEG EPROM there will be 32 – 16k Pages and with an 8 MEG EPROM there will be 64 pages of PROM. With an 8 meg EPROM you could put 63 – 16k

cartridge games in one cartridge (the first page, Page 0, is where you would put the menu).

I did not want to restrict the cartridge to just 16k cartridge games, so I modified the board so that it would be able to shut itself off and go to C64 basic, or load a bigger game, and even multipart games. But we can get into that later when I cover the C64 section.

### I needed more than 1 meg of ROM space for the C128, so I made an adapter for the Internal ROM socket. With the adapter it will allow the use of a 32-pin EPROM in a 28-pin

socket. Like the C64 Cartridge, it will accommodate any one of the high capacity EPROMs.

### I stopped using the I/O at the Expansion Port because it interfered with some cartridge programs. The C128 has two unused I/Os, pin 12 and pin 14 of U3 (74LS138). I chose pin 12

that is available at $D700 in the I/O section. With the I/O in C128 memory active you can READ or WRITE to address $D700 and the voltage at pin 12 of U3 will transition from high to low. This I/O is used to select one of the possible pages of the EPROM (0-32). All you have to do is put the page number (in HEX format) on the data buss and write to $D700 and the EPROM will

### switch to the page you selected. For example:

LDA #$1B | ; PAGE 27

### NOP NOP

STA $D700 | ; TRANSITION PIN 12

### The NOPs are to allow enough time for the page number to appear on the data buss before you transition pin 12. Another example (this is the way I do it):

LDA #$1B | ; PAGE 27

### STA $D700 STA $D700

### HOW IT WORKS

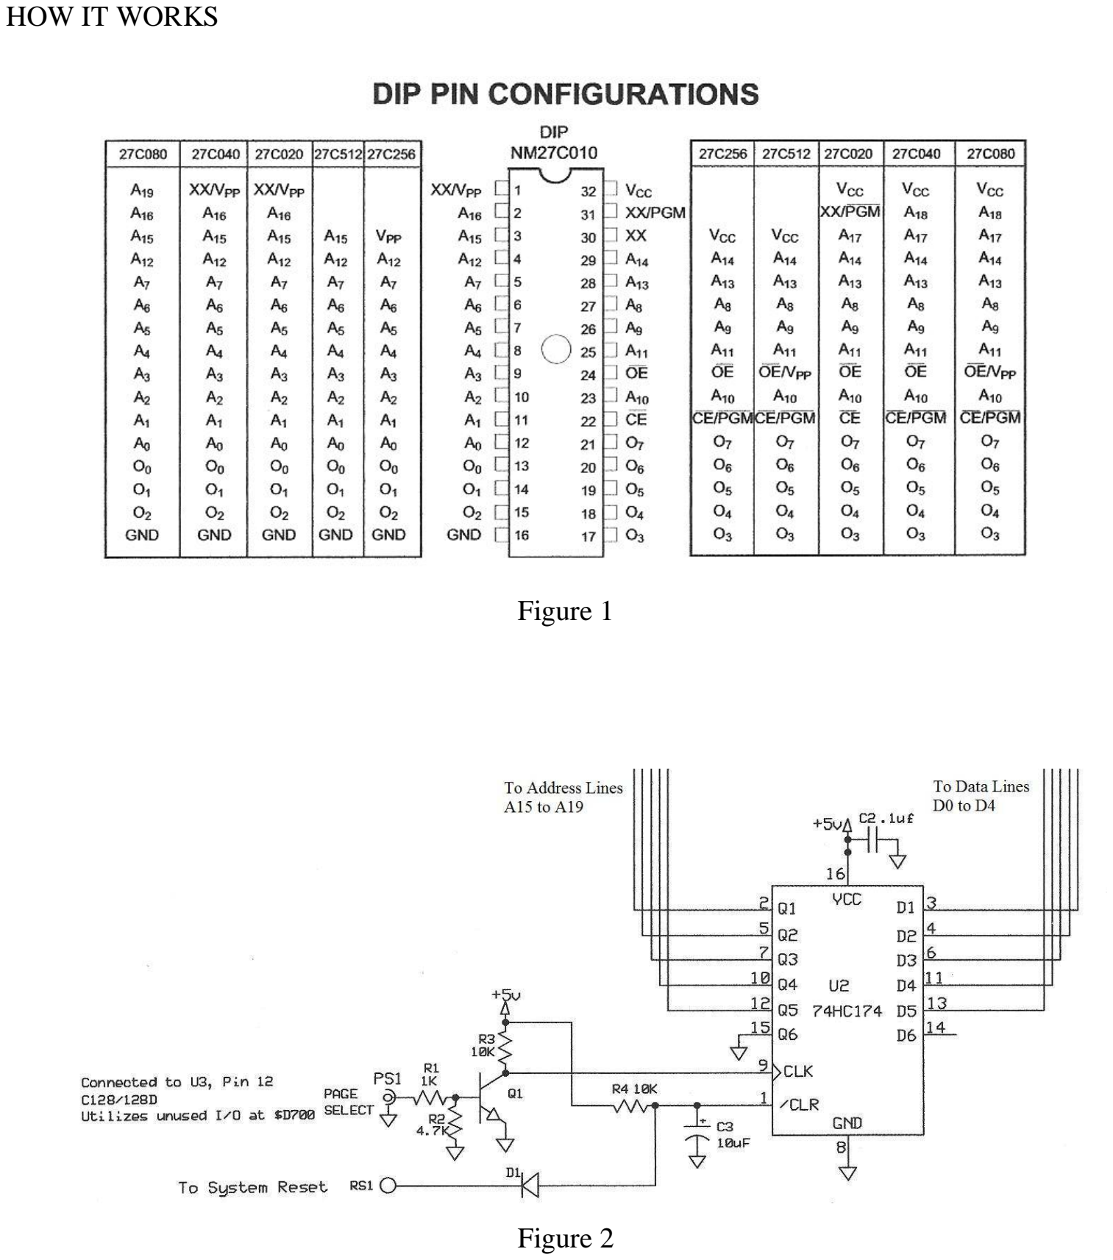
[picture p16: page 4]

### Figure 1

### Figure 2

### The Internal ROM area will use only 32k of memory space ($8000 - $FFFF). If you look

at a schematic of the C128, the Internal ROM area (U36) has only 15 address lines (A0-A14). That is the same as a 32k EPROM (27256). Below is the total number of address lines for the high capacity EPROMs. Refer to Figure 1.

27010 | 17 adrs lines | A0-A16 | 1 meg
27020 | 18 adrs lines | A0-A17 | 2 meg
27040 | 19 adrs lines | A0-A18 | 4 meg
27080 | 20 adrs lines | A0-A19 | 8 meg

### To use the other areas of the larger EPROMs, we have to control the remaining address

lines. I have done that by using a D-type Flip-Flop for each extra address line. Refer to Figure 2. The page number is placed on the data buss and the binary value will appear at the D inputs of the HEX D Flip-Flop (27HC174). When the clock input is transitioned from a low to a high the data at the D inputs will be transferred to the Q outputs and the address lines of the EPROM.

The transistor in figure 2 is used as an inverter because the signal from U3 pin-12 transitions from high to low, the clock input on the HEX D flip-flop requires a low to high transition.

Resistor R4 and C3 are used to hold the Flip-Flops in reset mode during power up. That way the

### ROM will always come up on Page 0 at power up. (Optional) If you connect RS1 to system

reset, the ROM will be reset to Page 0 every time you push the reset button.

### Here is how it looks with a 27010 (1 MEG EPROM):

Pg HEX | A16 A15
Page 00 | 0 | 0 | 32K x 8
Page 01 | 0 | 1 | 32K x 8
Page 02 | 1 | 0 | 32K x 8
Page 03 | 1 | 1 | 32K x 8
Total | 128K x 8

### Here is how it looks with a 27020 (2 MEG EPROM):

Pg HEX | A17 A16 A15
Page 00 | 0 | 0 | 0 | 32K x 8
Page 01 | 0 | 0 | 1 | 32K x 8
Page 02 | 0 | 1 | 0 | 32K x 8
Page 03 | 0 | 1 | 1 | 32K x 8
Page 04 | 1 | 0 | 0 | 32K x 8
Page 05 | 1 | 0 | 1 | 32K x 8
Page 06 | 1 | 1 | 0 | 32K x 8
Page 07 | 1 | 1 | 1 | 32K x 8
Total | 256K x 8

### Here is how it looks with a 27040 (4 MEG EPROM):

Pg HEX | A18 A17 A16 A15
Page 00 | 0 | 0 | 0 | 0 | 32K x 8
Page 01 | 0 | 0 | 0 | 1 | 32K x 8
Page 02 | 0 | 0 | 1 | 0 | 32K x 8
Page 03 | 0 | 0 | 1 | 1 | 32K x 8
Page 04 | 0 | 1 | 0 | 0 | 32K x 8
Page 05 | 0 | 1 | 0 | 1 | 32K x 8
Page 06 | 0 | 1 | 1 | 0 | 32K x 8
Page 07 | 0 | 1 | 1 | 1 | 32K x 8
Page 08 | 1 | 0 | 0 | 0 | 32K x 8
Page 09 | 1 | 0 | 0 | 1 | 32K x 8
Page 0A | 1 | 0 | 1 | 0 | 32K x 8
Page 0B | 1 | 0 | 1 | 1 | 32K x 8
Page 0C | 1 | 1 | 0 | 0 | 32K x 8
Page 0D | 1 | 1 | 0 | 1 | 32K x 8
Page 0E | 1 | 1 | 1 | 0 | 32K x 8
Page 0F | 1 | 1 | 1 | 1 | 32K x 8
Total | | | | | 512K x 8

### Here is how it looks with a 27080 (8 MEG EPROM):

Pg HEX | A19 A18 A17 A16 A15
Page 00 | 0 | 0 | 0 | 0 | 0 | 32K x 8
Page 01 | 0 | 0 | 0 | 0 | 1 | 32K x 8
Page 02 | 0 | 0 | 0 | 1 | 0 | 32K x 8
Page 03 | 0 | 0 | 0 | 1 | 1 | 32K x 8
Page 04 | 0 | 0 | 1 | 0 | 0 | 32K x 8
Page 05 | 0 | 0 | 1 | 0 | 1 | 32K x 8
Page 06 | 0 | 0 | 1 | 1 | 0 | 32K x 8
Page 07 | 0 | 0 | 1 | 1 | 1 | 32K x 8
Page 08 | 0 | 1 | 0 | 0 | 0 | 32K x 8
Page 09 | 0 | 1 | 0 | 0 | 1 | 32K x 8
Page 0A | 0 | 1 | 0 | 1 | 0 | 32K x 8
Page 0B | 0 | 1 | 0 | 1 | 1 | 32K x 8
Page 0C | 0 | 1 | 1 | 0 | 0 | 32K x 8
Page 0D | 0 | 1 | 1 | 0 | 1 | 32K x 8
Page 0E | 0 | 1 | 1 | 1 | 0 | 32K x 8
Page 0F | 0 | 1 | 1 | 1 | 1 | 32K x 8
Page 10 | 1 | 0 | 0 | 0 | 0 | 32K x 8
Page 11 | 1 | 0 | 0 | 0 | 1 | 32K x 8
Page 12 | 1 | 0 | 0 | 1 | 0 | 32K x 8
Page 13 | 1 | 0 | 0 | 1 | 1 | 32K x 8
Page 14 | 1 | 0 | 1 | 0 | 0 | 32K x 8
Page 15 | 1 | 0 | 1 | 0 | 1 | 32K x 8
Page 16 | 1 | 0 | 1 | 1 | 0 | 32K x 8
Page 17 | 1 | 0 | 1 | 1 | 1 | 32K x 8
Page 18 | 1 | 1 | 0 | 0 | 0 | 32K x 8
Page 19 | 1 | 1 | 0 | 0 | 1 | 32K x 8
Page 1A | 1 | 1 | 0 | 1 | 0 | 32K x 8
Page 1B | 1 | 1 | 0 | 1 | 1 | 32K x 8
Page 1C | 1 | 1 | 1 | 0 | 0 | 32K x 8
Page 1D | 1 | 1 | 1 | 0 | 1 | 32K x 8
Page 1E | 1 | 1 | 1 | 1 | 0 | 32K x 8
Page 1F | 1 | 1 | 1 | 1 | 1 | 32K x 8
Total | | | | | | 1024K x 8

### AUTO START AND PROGRAM FUNCTION KEYS

The first thing you have to do is make the programs easy to access. The C128 has an auto boot routine during power up and reset for cartridge, Internal ROM and disk (device 8). We will just cover the Internal ROM.

### During the power up or reset routine your computer will look for CBM at the beginning of Internal ROM $8000 or $C000. Here is what it will look like:

### Bytes Description

### x000-02 Cold start entry x003-05 Warm start entry x006 ID byte, $00 for due nothing, anything else for auto-start x007-09 “CBM” string

### Note: x = $8 (middle) or $C (high)

### $8000 EA EA EA 4C 0A 80 FF 43 42 4D

$8000 NOP | ;COLD START

### $8001 NOP $8002 NOP

$8003 JMP $800A | ;WARM START
$8006 FF | ;ID, $00 OR $01
$8007 ‘CBM’ | ;CBM STRING
$800A | ;START OF PGM

It will make note in lower RAM that there is an auto-start in Internal ROM and return to the ROM during the PHENIOX routine and run the program at $800A.

The program at $800A will reprogram one of the Function Keys that will jump to the MENU of all the programs in your Internal ROM. Here is the Merlin listing for the program, you can find

### the source code on disk:

1
2 | ***********************************************
3 | * re-program a function key | *
4 | * x reg = f-key no. | *
5 | * y reg = length of string | *
6 | * acu = pointer to location of string $24/$25 *
7 | * store bank no. of string loc in $26 | *
8 | ***********************************************
9
10 | STLOC | = | $24 | ;string location
11 | BANK | = | $26 | ;bank loc. of string
12 | PGSW | = | $D700 | ;switch page of int. ROM
13 | PFKEY | = | $FF65 | ;routine to reprogram
14 | ; f-keys
15 | CONFIG | = | $FF00 | ;change memory
16 | ; configuration
17
18 | ORG | $8000
19
8000: EA | 20 | NOP
8001: EA | 21 | NOP
8002: EA | 22 | NOP
8003: 4C 0A 80 23 | JMP | PGKEY
8006: FF | 24 | HEX | FF
8007: 43 42 4D 25 | TXT | 'cbm'
26
800A: AD 00 FF 27 | PGKEY | LDA | CONFIG | ;get configuration
800D: 48 | 28 | PHA | ;put on stack
800E: A9 06 | 29 | LDA | #$06 | ;int ROM & KERNAL
8010: 8D 00 FF 30 | STA | CONFIG | ;set config
8013: 85 26 | 31 | STA | BANK | ;store bank no. in $26
8015: A9 36 | 32 | LDA | #<STR | ;get lo byte of string loc
8017: 85 24 | 33 | STA | STLOC | ;store in $24
8019: A9 80 | 34 | LDA | #>STR | ;get hi byte of string loc
801B: 85 25 | 35 | STA | STLOC+1 | ;store in $25
801D: A2 0A | 36 | LDX | #$0A | ;Fkey number to prg
37 | ; #$0A is help key
801F: A0 08 | 38 | LDY | #$08 | ;no. of bytes for string
8021: A9 24 | 39 | LDA | #STLOC | ;loc. of string
8023: 20 65 FF 40 | JSR | PFKEY | ;program f-key
8026: A2 0F | 41 | LDX | #$0F | ;no. of bytes to relocate
8028: BD 3E 80 42 | LOOP | LDA | JPMENU,X | ;get byte
802B: 9D A0 10 43 | STA | $10A0,X | ;store byte
802E: CA | 44 | DEX | ;decrease X by 1
802F: 10 F7 | 45 | BPL | LOOP | ;loop until finished
8031: 68 | 46 | PLA | ;get org. config
8032: 8D 00 FF 47 | STA | CONFIG | ;set config
8035: 60 | 48 | RTS | ;return
49

50 | *********************************
51 | * new f-key definition, 8 bytes *
52 | *********************************
53
8036: 53 59 53 54 | STR | TXT | 'sys4256',0d ;this will system to
8039: 34 32 35 36 0D
| 55 | | | | ; jpmenu at loc. $10A0
| 56
57 | ************************************
58 | * ml routine that will jmp to menu *
59 | ************************************
| 60
803E: A9 06 | 61 | JPMENU | LDA | #$06 | ;internal ROM & kernal
8040: 8D 00 FF 62 | STA | CONFIG | ;set configuration
8043: A9 00 | 63 | | LDA | #$00 | ;page 0
8045: 8D 00 D7 64 | STA | PGSW | ;switch page
8048: 8D 00 D7 65 | STA | PGSW
804B: 4C 4E 80 66 | JMP | MENU | ;jmp to internal ROM menu
| 67
804E: EA | 68 | MENU | NOP | | ;append menu here
| 69

### Place the object code for the above routine at the beginning of a 27256 EPROM, plug it

into the Internal ROM socket and turn the computer on. It will reprogram the HELP key, when you push the HELP key, the computer will attempt to run the menu if you have one in ROM. The

### line marked in red is what determines which function key is programmed. Hex numbers $01 -$08 cover the function keys, $09 will reprogram SHIFT RUN/STOP and $0A will reprogram the HELP key

### Below is what the MENU in the Megabit C128 Internal ROM looks like. You can find the

Merlin source listing on the disk.

1
2 | JMPLDR | = | $10E0 | ;jump to loader
3 | PRESET | = | $10F0 | ;program reset
4 | WRMSTRT = | $4003 | ;warm basic start
5 | PRINT | = | $C00C | ;print to screen
6 | PGSW | = | $D700 | ;switch page of Int ROM
7 | CONFIG | = | $FF00 | ;set memory configuration
8 | STOP | = | $FFE1 | ;check stop key
9 | GETIN | = | $FFE4 | ;get a char in acu
10 | RESET | = | $FFFC | ;hard reset
11
12 | ORG | $1300
13
1300: A2 FF | 14 | LDX | #$FF
1302: 9A | 15 | TXS
1303: A2 16 | 16 | LDX | #$16 | ;internal rom with i/o
1305: 8E 01 D5 17 | STX | $D501 | ; at $ff01
1308: E8 | 18 | INX | ;internal ROM w/o i/o
1309: 8E 02 D5 19 | STX | $D502 | ; at $ff02

130C: 58 | 20 | | CLI
130D: D8 | 21 | | CLD
130E: A5 D7 | 22 | | LDA | $D7 | ;ck for 40 or 80 col scrn
1310: F0 0D | 23 | | BEQ | SCN40 | ;40 col scrn
1312: AD 11 D0 24 | LDA | $D011 | ;80 col scrn
1315: 29 6F | 25 | | AND | #$6F | ;switch to fast mode
1317: 8D 11 D0 26 | STA | $D011 | ; and blank 40-col
131A: A9 01 | 27 | | LDA | #$01
131C: 8D 30 D0 28 | STA | $D030
131F: A9 00 | 29 | SCN40 | LDA | #$00
1321: 85 C6 | 30 | | STA | $C6
1323: 85 C7 | 31 | | STA | $C7
1325: 85 FD | 32 | | STA | $FD | ;clr menu counter
1327: A2 0A | 33 | | LDX | #$0A
1329: BD 29 15 34 | LOOP1 | LDA | LDRSTG,X
132C: 9D E0 10 35 | STA | JMPLDR,X
132F: CA | 36 | | DEX
1330: 10 F7 | 37 | | BPL | LOOP1
1332: 20 C3 14 38 | NEWSC | JSR | PRTSCN
1335: 20 E1 FF 39 | GETK | JSR | STOP
1338: F0 2D | 40 | | BEQ | QUIT
133A: 20 E4 FF 41 | JSR | GETIN
133D: F0 F6 | 42 | | BEQ | GETK
133F: C9 20 | 43 | | CMP | #$20
1341: F0 16 | 44 | | BEQ | NXMN | ;next menu
1343: C9 41 | 45 | | CMP | #$41 | ;is it below #$41?
1345: 90 EE | 46 | | BCC | GETK | ;yes, then go back
1347: C9 60 | 47 | | CMP | #$60 | ;is it above #$60?
1349: B0 EA | 48 | | BCS | GETK | ;yes, then go back
134B: 38 | 49 | | SEC
134C: E9 41 | 50 | | SBC | #$41 | ; subtract #$41
134E: 0A | 51 | | ASL | | ;multi by 2
134F: AA | 52 | | TAX | | ;trans acu to X
1350: BD 83 13 53 | LDA | CMD+1,X | ;get adrs loc hi
1353: 48 | 54 | | PHA | | ;put on stack
1354: BD 82 13 55 | LDA | CMD,X | ;get adrs loc lo
1357: 48 | 56 | | PHA | | ;put on stack
1358: 60 | 57 | | RTS | | ;CMD entry
| 58
1359: E6 FD | 59 | NXMN | INC | $FD | ;incr menu ctr
135B: A5 FD | 60 | | LDA | $FD
135D: C9 03 | 61 | | CMP | #$03 | ;is it #$03?
135F: D0 D1 | 62 | | BNE | NEWSC | ;no, then prt nxt menu
1361: A9 00 | 63 | CLR | LDA | #$00
1363: 85 FD | 64 | | STA | $FD | ;clr menu ctr
1365: F0 CB | 65 | | BEQ | NEWSC | ;print menu 1
| 66
1367: A9 93 | 67 | QUIT | LDA | #$93 | ;clr screen
1369: 20 0C C0 68 | JSR | PRINT
136C: A2 07 | 69 | | LDX | #$07 | ;trans basic jump
136E: BD 7A 13 70 | LOOP2 | LDA | TOBAS,X | ;to program reset
1371: 9D F0 10 71 | STA | PRESET,X
1374: CA | 72 | | DEX
1375: 10 F7 | 73 | | BPL | LOOP2
1377: 4C F0 10 74 | JMP | PRESET
| 75
137A: A9 00 | 76 | TOBAS | LDA | #$00

137C: 8D 00 FF 77 | STA | CONFIG
137F: 4C 03 40 78 | JMP | WRMSTRT
79
1382: F6 13 | 80 | CMD | DA | MER-1 | ;merlin 128
1384: FF 13 | 81 | | DA | PRO-1 | ;promos 2.0
1386: 08 14 | 82 | | DA | DE-1 | ;my disk editor
1388: 0B 14 | 83 | | DA | FK-1 | ;function key display
138A: 0E 14 | 84 | | DA | VW-1 | ;vizawrite 128
138C: 17 14 | 85 | | DA | VS-1 | ;vizastar 128
138E: 20 14 | 86 | | DA | SQR-1 | ;seq file reader
1390: 23 14 | 87 | | DA | BGEN-1 | ;begin & end adrs
1392: 26 14 | 88 | | DA | FTFC-1 | ;fastrac file copier
1394: 2F 14 | 89 | | DA | DIRE-1 | ;directory editor
1396: 38 14 | 90 | | DA | CO80-1 | ;color 80col
1398: 3B 14 | 91 | | DA | DM-1 | ;basic data maker
139A: 3E 14 | 92 | | DA | MON64-1 | ;monitor 64
139C: 47 14 | 93 | | DA | ZED-1 | ;zed 128
139E: 50 14 | 94 | | DA | MERGP-1 | ;basic merge +
13A0: 53 14 | 95 | | DA | MAVFC-1 | ;maverick file copy
13A2: 5C 14 | 96 | | DA | MAVTE-1 | ;maverick track editor
13A4: 65 14 | 97 | | DA | SGL41-1 | ;single 41 data copy
13A6: 6E 14 | 98 | | DA | DUL41-1 | ;dual 41 data copy
13A8: 77 14 | 99 | | DA | SGLNY-1 | ;single nybbler
13AA: 80 14 | 100 | | DA | DULNY-1 | ;dual nybbler
13AC: 89 14 | 101 | | DA | SGL81-1 | ;single 81 data copy
13AE: 92 14 | 102 | | DA | MAVFT-1 | ;maverick file tracer
13B0: 9B 14 | 103 | | DA | MAVTS-1 | ;maverick track & sector ed
13B2: A4 14 | 104 | | DA | VDC-1 | ;64k vdc ram test
13B4: AD 14 | 105 | | DA | REU-1 | ;reu test
13B6: 34 13 | 106 | | DA | GETK-1 | ;fill
13B8: BF 13 | 107 | | DA | BAS8-1 | ;basic 8, \ key
13BA: 34 13 | 108 | | DA | GETK-1 | ;fill
13BC: C7 13 | 109 | | DA | SERV-1 | ;servant, ^ key
13BE: CF 13 | 110 | | DA | KEYD-1 | ;keydos, _ key
| 111
112 ***** loaders for 32k programs *****
| 113
13C0: 20 D8 13 114 BAS8 | JSR | TROM
13C3: A9 0D | 115 | | LDA | #$0D | ;ld page no
13C5: 4C F0 10 116 | JMP | PRESET
| 117
13C8: 20 D8 13 118 SERV | JSR | TROM
13CB: A9 0E | 119 | | LDA | #$0E | ;ld page no
13CD: 4C F0 10 120 | JMP | PRESET
| 121
13D0: 20 D8 13 122 KEYD | JSR | TROM
13D3: A9 0F | 123 | | LDA | #$0F | ;ld page no
13D5: 4C F0 10 124 | JMP | PRESET
| 125
13D8: A9 93 | 126 TROM | LDA | #$93 | ;clr the scrn
13DA: 20 0C C0 127 | JSR | PRINT
13DD: A2 0D | 128 | | LDX | #$0D
13DF: BD E9 13 129 LOOP3 | LDA | TOROM,X
13E2: 9D F0 10 130 | STA | PRESET,X
13E5: CA | 131 | | DEX
13E6: 10 F7 | 132 | | BPL | LOOP3
13E8: 60 | 133 | | RTS

134
13E9: 8D 00 D7 135 TOROM | STA | PGSW
13EC: 8D 00 D7 136 | STA | PGSW
13EF: A9 00 | 137 | LDA | #$00
13F1: 8D 00 FF 138 | STA | CONFIG
13F4: 6C FC FF 139 | JMP | (RESET)
| 140
141 ***** to loaders of smaller programs *****
| 142
13F7: A9 01 | 143 MER | LDA | #$01 | ;ld page no
13F9: A2 00 | 144 | LDX | #$00 | ;ld low byte
13FB: A0 80 | 145 | LDY | #$80 | ;ld high byte
13FD: 4C B7 14 146 | JMP | GO | ;jmp to merlin
| 147
1400: A9 03 | 148 PRO | LDA | #$03 | ;ld page no
1402: A2 00 | 149 | LDX | #$00 | ;ld low byte
1404: A0 90 | 150 | LDY | #$90 | ;ld high byte
1406: 4C B7 14 151 | JMP | GO | ;jmp to promos
| 152
1409: 4C 00 B0 153 DE | JMP | $B000 | ;jmp to disk edit
| 154
140C: 4C 00 97 155 FK | JMP | $9700 | ;jmp to fkeys
| 156
140F: A9 0A | 157 VW | LDA | #$0A | ;ld page no
1411: A2 00 | 158 | LDX | #$00 | ;ld low byte
1413: A0 85 | 159 | LDY | #$85 | ;ld high byte
1415: 4C B7 14 160 | JMP | GO | ;jmp to vizawrite
| 161
1418: A9 0C | 162 VS | LDA | #$0C | ;ld page no
141A: A2 00 | 163 | LDX | #$00 | ;ld low byte
141C: A0 90 | 164 | LDY | #$90 | ;ld high byte
141E: 4C B7 14 165 | JMP | GO | ;jmp to vizastar
| 166
1421: 4C 00 9D 167 SQR | JMP | $9D00 | ;jmp to seq reader
| 168
1424: 4C 00 A4 169 BGEN | JMP | $A400 | ;jmp to begin & end
| 170
1427: A9 03 | 171 FTFC | LDA | #$03 | ;ld page no
1429: A2 00 | 172 | LDX | #$00 | ;ld low byte
142B: A0 91 | 173 | LDY | #$91 | ;ld high byte
142D: 4C B7 14 174 | JMP | GO | ;jmp to ft file copy
| 175
1430: A9 02 | 176 DIRE | LDA | #$02 | ;ld page no
1432: A2 00 | 177 | LDX | #$00 | ;ld low byte
1434: A0 81 | 178 | LDY | #$81 | ;ld high byte
1436: 4C B7 14 179 | JMP | GO | ;jmp to dir edit
| 180
1439: 4C 00 9A 181 CO80 | JMP | $9A00 | ;jmp to color80
| 182
143C: 4C 90 A4 183 DM | JMP | $A490 | ;jmp to data maker
| 184
143F: A9 02 | 185 MON64 | LDA | #$02 | ;ld page no
1441: A2 00 | 186 | LDX | #$00 | ;ld low byte
1443: A0 80 | 187 | LDY | #$80 | ;ld high byte
1445: 4C B7 14 188 | JMP | GO | ;jmp to monitor64
| 189
1448: A9 02 | 190 ZED | LDA | #$02 | ;ld page no

144A: A2 00 | 191 | LDX | #$00 | ;ld low byte
144C: A0 82 | 192 | LDY | #$82 | ;ld high byte
144E: 4C B7 14 193 | JMP | GO | ;jmp to zed 128
| 194
1451: 4C 0E 93 195 MERGP | JMP | $930E | ;jmp to merge +
| 196
1454: A9 08 | 197 MAVFC | LDA | #$08 | ;ld page no
1456: A2 00 | 198 | LDX | #$00 | ;ld low byte
1458: A0 80 | 199 | LDY | #$80 | ;ld high byte
145A: 4C B7 14 200 | JMP | GO | ;jmp to mav file copy
| 201
145D: A9 04 | 202 MAVTE | LDA | #$04 | ;ld page no
145F: A2 00 | 203 | LDX | #$00 | ;ld low byte
1461: A0 80 | 204 | LDY | #$80 | ;ld high byte
1463: 4C B7 14 205 | JMP | GO | ;jmp to mav trk edit
| 206
1466: A9 07 | 207 SGL41 | LDA | #$07 | ;ld page no
1468: A2 00 | 208 | LDX | #$00 | ;ld low byte
146A: A0 90 | 209 | LDY | #$90 | ;ld high byte
146C: 4C B7 14 210 | JMP | GO | ;jmp to 41 data copy
| 211
146F: A9 06 | 212 DUL41 | LDA | #$06 | ;ld page no
1471: A2 00 | 213 | LDX | #$00 | ;ld low byte
1473: A0 90 | 214 | LDY | #$90 | ;ld high byte
1475: 4C B7 14 215 | JMP | GO | ;jmp to dual data copy
| 216
1478: A9 05 | 217 SGLNY | LDA | #$05 | ;ld page no
147A: A2 00 | 218 | LDX | #$00 | ;ld low byte
147C: A0 90 | 219 | LDY | #$90 | ;ld high byte
147E: 4C B7 14 220 | JMP | GO | ;jmp to sgl nybbler
| 221
1481: A9 05 | 222 DULNY | LDA | #$05 | ;ld page no
1483: A2 00 | 223 | LDX | #$00 | ;ld low byte
1485: A0 91 | 224 | LDY | #$91 | ;ld high byte
1487: 4C B7 14 225 | JMP | GO | ;jmp to dual nybbler
| 226
148A: A9 04 | 227 SGL81 | LDA | #$04 | ;ld page no
148C: A2 00 | 228 | LDX | #$00 | ;ld low byte
148E: A0 81 | 229 | LDY | #$81 | ;ld high byte
1490: 4C B7 14 230 | JMP | GO | ;jmp to 81 data copy
| 231
1493: A9 06 | 232 MAVFT | LDA | #$06 | ;ld page no
1495: A2 00 | 233 | LDX | #$00 | ;ld low byte
1497: A0 91 | 234 | LDY | #$91 | ;ld high byte
1499: 4C B7 14 235 | JMP | GO | ;jmp to file tracer
| 236
149C: A9 07 | 237 MAVTS | LDA | #$07 | ;ld page no
149E: A2 00 | 238 | LDX | #$00 | ;ld low byte
14A0: A0 91 | 239 | LDY | #$91 | ;ld high byte
14A2: 4C B7 14 240 | JMP | GO | ;jmp to trk & sec edit
| 241
14A5: A9 08 | 242 VDC | LDA | #$08 | ;ld page no
14A7: A2 00 | 243 | LDX | #$00 | ;ld low byte
14A9: A0 81 | 244 | LDY | #$81 | ;ld high byte
14AB: 4C B7 14 245 | JMP | GO | ;jmp to vdc ram test
| 246
14AE: A9 08 | 247 REU | LDA | #$08 | ;ld page no

14B0: A2 00 | 248 | LDX | #$00 | ;ld low byte
14B2: A0 82 | 249 | LDY | #$82 | ;ld high byte
14B4: 4C B7 14 250 | JMP | GO | ;jmp to reu test
| 251
14B7: 8D E1 10 252 GO | STA | $10E1
14BA: 8E E9 10 253 | STX | $10E9
14BD: 8C EA 10 254 | STY | $10EA
14C0: 4C E0 10 255 | JMP | $10E0 | ;jmp to loader
| 256
14C3: A5 FD | 257 PRTSCN | LDA | $FD
14C5: C9 00 | 258 | CMP | #$00
14C7: F0 0B | 259 | BEQ | MU1 | ;menu 1
14C9: C9 01 | 260 | CMP | #$01
14CB: F0 12 | 261 | BEQ | MU2 | ;menu 2
14CD: C9 02 | 262 | CMP | #$02
14CF: F0 19 | 263 | BEQ | MU3 | ;menu 3
14D1: 4C 61 13 264 | JMP | CLR
| 265
14D4: A9 34 | 266 MU1 | LDA | #<MENU1 | ;get lo byte of menu1
14D6: 85 FA | 267 | STA | $FA | ;store in $fa
14D8: A9 15 | 268 | LDA | #>MENU1 | ;get hi byte of menu1
14DA: 85 FB | 269 | STA | $FB | ;store in $fb
14DC: 4C F2 14 270 | JMP | PRT | ;prt menu1
| 271
14DF: A9 CC | 272 MU2 | LDA | #<MENU2
14E1: 85 FA | 273 | STA | $FA
14E3: A9 16 | 274 | LDA | #>MENU2
14E5: 85 FB | 275 | STA | $FB
14E7: 4C F2 14 276 | JMP | PRT
| 277
14EA: A9 64 | 278 MU3 | LDA | #<MENU3
14EC: 85 FA | 279 | STA | $FA
14EE: A9 18 | 280 | LDA | #>MENU3
14F0: 85 FB | 281 | STA | $FB
14F2: A0 00 | 282 PRT | LDY | #$00
14F4: B1 FA | 283 LOOP4 | LDA | ($FA),Y
14F6: F0 10 | 284 | BEQ | SKIP2
14F8: C8 | 285 | INY
14F9: C0 00 | 286 | CPY | #$00
14FB: D0 02 | 287 | BNE | SKIP
14FD: E6 FB | 288 | INC | $FB
14FF: C9 FF | 289 SKIP | CMP | #$FF
1501: F0 06 | 290 | BEQ | SKIP1
1503: 20 0C C0 291 | JSR | PRINT
1506: D0 EC | 292 | BNE | LOOP4
1508: 60 | 293 SKIP2 | RTS
| 294
1509: 84 FC | 295 SKIP1 | STY | $FC
150B: A5 D7 | 296 | LDA | $D7
150D: D0 01 | 297 | BNE | SKIP5
150F: C8 | 298 | INY
1510: B1 FA | 299 SKIP5 | LDA | ($FA),Y
1512: AA | 300 | TAX
1513: E0 00 | 301 | CPX | #$00
1515: F0 08 | 302 | BEQ | NOSPC
1517: A9 20 | 303 | LDA | #$20
1519: 20 0C C0 304 NXSP | JSR | PRINT

151C: CA | 305 | DEX
151D: 10 FA | 306 | BPL | NXSP
151F: E6 FC | 307 NOSPC | INC | $FC
1521: E6 FC | 308 | INC | $FC
1523: A4 FC | 309 | LDY | $FC
1525: D0 CD | 310 | BNE | LOOP4
1527: F0 CB | 311 | BEQ | LOOP4
312
313 ***** routine to loaders ***** 314
1529: A9 00 | 315 LDRSTG | LDA | #$00
152B: 8D 00 D7 316 | STA | PGSW
152E: 8D 00 D7 317 | STA | PGSW
1531: 4C 00 00 318 | JMP | $0000
319
320 ************************************************ 321 * ff = end of sentence, next is 80-col spaces, *
322 * next is 40-col spaces, 12 = reverse print | *
323 * 00 before ff = end of menu | *
324 ************************************************ 325
1534: 93 8E 0D 326 MENU1 | HEX | 93,8E,0D,0D,FF,1E,0A,12
153C: 20 49 4E 327 | TXT | ' internal rom menu '0d,0d,ff,20,0c
1554: 42 59 20 328 | TXT | 'by d.c. newbury'0d,0d,ff,22,0e
1568: 4D 45 4E 329 | TXT | 'menu 1 of 3'0d,0d,ff,14,00
330
1578: 41 29 20 331 | TXT | 'a) merlin c128 | '
158C: 42 29 20 332 | TXT | 'b) promos 2.0 | '0d,ff,14,00
333
15A4: 43 29 20 334 | TXT | 'c) my disk editor | '
15B8: 44 29 20 335 | TXT | 'd) function keys | '0d,ff,14,00
336
15D0: 45 29 20 337 | TXT | 'e) viza write 128 | '
15E4: 46 29 20 338 | TXT | 'f) viza star 128 | '0d,ff,14,00
339
15FC: 47 29 20 340 | TXT | 'g) seq reader 128 | '
1610: 48 29 20 341 | TXT | 'h) begin & end adrs '0d,ff,14,00
342
1628: 49 29 20 343 | TXT | 'i) fastrac filecopy '
163C: 4A 29 20 344 | TXT | 'j) directory editor '0d,ff,14,00
345
1654: 4B 29 20 346 | TXT | 'k) color 80 col | '
1668: 4C 29 20 347 | TXT | 'l) basic data maker '0d,ff,14,00
348
1680: 4D 29 20 349 | TXT | 'm) monitor 64 | '0d,0d,ff,1e,0a,12
350
169A: 20 50 52 351 | TXT | ' press stop to exit '0d,ff,1c,08,12
16B3: 20 50 52 352 | TXT | ' press space next menu '0d,00
353
354
16CC: 93 8E 0D 355 MENU2 | HEX | 93,8E,0D,0D,FF,1E,0A,12
16D4: 20 49 4E 356 | TXT | ' internal rom menu '0d,0d,ff,20,0c
16EC: 42 59 20 357 | TXT | 'by d.c. newbury'0d,0d,ff,22,0e
1700: 4D 45 4E 358 | TXT | 'menu 2 of 3'0d,0d,ff,14,00
359
1710: 4E 29 20 360 | TXT | 'n) zed 128 | '
1724: 4F 29 20 361 | TXT | 'o) basic merge + | '0d,ff,14,00

362
173C: 50 29 20 363 | TXT | 'p) mav file copy | '
1750: 51 29 20 364 | TXT | 'q) mav track editor '0d,ff,14,00
365
1768: 52 29 20 366 | TXT | 'r) sgl 41 data copy '
177C: 53 29 20 367 | TXT | 's) dul 41 data copy '0d,ff,14,00
368
1794: 54 29 20 369 | TXT | 't) single nybbler | '
17A8: 55 29 20 370 | TXT | 'u) dual nybbler | '0d,ff,14,00
371
17C0: 56 29 20 372 | TXT | 'v) sgl 81 data copy '
17D4: 57 29 20 373 | TXT | 'w) mav file tracer '0d,ff,14,00
374
17EC: 58 29 20 375 | TXT | 'x) mav trk&sec edit '
1800: 59 29 20 376 | TXT | 'y) 64k vdc ram test '0d,ff,14,00
377
1818: 5A 29 20 378 | TXT | 'z) reu test | '0d,0d,ff,1e,0a,12
379
1832: 20 50 52 380 | TXT | ' press stop to exit '0d,ff,1c,08,12
184B: 20 50 52 381 | TXT | ' press space next menu '0d,00
382
383
1864: 93 8E 0D 384 MENU3 | HEX | 93,8E,0D,0D,FF,1E,0A,12
186C: 20 49 4E 385 | TXT | ' internal rom menu '0d,0d,ff,20,0c
1884: 42 59 20 386 | TXT | 'by d.c. newbury'0d,0d,ff,22,0e
1898: 4D 45 4E 387 | TXT | 'menu 3 of 3'0d,0d,ff,14,00
388
18A8: 5C 29 20 389 | TXT | '£) basic 8 | '
18BC: 5E 29 20 390 | TXT | '↑) servant | '0d,ff,14,00
391
18D4: 5F 29 20 392 | TXT | '←) key dos | '
18E8: 20 20 20 393 | TXT | ' | '0d,ff,14,00
394
1900: 20 20 20 395 | TXT | ' | '
1914: 20 20 20 396 | TXT | ' | '0d,ff,14,00
397
192C: 20 20 20 398 | TXT | ' | '
1940: 20 20 20 399 | TXT | ' | '0d,ff,14,00
400
1958: 20 20 20 401 | TXT | ' | '
196C: 20 20 20 402 | TXT | ' | '0d,ff,14,00
403
1984: 20 20 20 404 | TXT | ' | '
1998: 20 20 20 405 | TXT | ' | '0d,ff,14,00
406
19B0: 20 20 20 407 | TXT | ' | '0d,0d,ff,1e,0a,12
408
19CA: 20 50 52 409 | TXT | ' press stop to exit '0d,ff,1c,08,12
19E3: 20 50 52 410 | TXT | ' press space next menu '0d,00
411

17

### You can load and run C128 programs or C64 programs from the Internal ROM area. But when you quit the C64 programs you will have to reset the computer to get back into C128

mode.

### You can run BASIC or ML programs from Internal ROM, C128 or C64. We will look at

loaders for the different types of programs. The C64 programs will have to be transferred to RAM first, then switched to C64 mode. You cannot get access to Internal ROM from C64 mode.

### There is something else that I need to mention about using programs in C64 mode. If the program is a large program that extends past the start of BASIC ($A000) or loads into the

beginning of that area, your program will be corrupted when you switch to C64 mode.

### When the C64 is initializing it will check RAM to find the end of basic RAM. When it bumps into ROM at $A000, $9FFF is the end of BASIC RAM. It checks RAM by saving a byte

at each location, stores a byte $55 and then checks to see if it is $55 and then puts the original byte back into the RAM location. When it gets to the edge of ROM ($A000), it tries to store byte $55 at that location and it will, only in RAM. When it reads that location it will read byte $94 instead of byte $55. It will stop checking RAM and move on without restoring the original byte at RAM location $A000. If there is important data at that location, your program will crash when it gets there. So keep that in mind when loading and starting C64 programs.

### The next program is a loader used to transfer ZED 128 to RAM from Internal ROM and

start the program with a basic one liner. The program is in two parts. The first part will transfer the loader to RAM at $0C00, jump to the RAM loader and continue on.

### At the end of the listing (line 92) is where the data is that tells the loader where the

program is in ROM ($85BF - $C814) and where in RAM ($1C01) it’s to be loaded.

### When finished transferring the program (line 74), it will set the computer up to run the

program. Starting at line 75 it will switch memory to RAM 0 and switch in all system ROMs. Then switch Internal ROM to page 0, if you don’t have the reset option of the adapter hooked up then you will have to switch in page 0 at the end of each loader before you start the program. That way when you push the reset button the Internal ROM will re-program the function key.

Next ZED 128 requires that the pre-configuration registers be restored to default values, then sets device 8 as the default disk drive. At line 90 you will see the basic one liner (sys7200 and return). To run it you will have to put the low byte of the address location – 1 in the X register and the high byte of the address location in the Y register and jump to $AFA5 (execute a line in basic). See the source listing at line 86, X = $7D and Y = $0C that would mean that the one liner is at $0C7E.

2
3 | ********************************
4 | * LOADER FOR ZED 128 | *
5 | ********************************
| 6 | *
| 7 | | ORG | $8200
| 8 | *
| 9 | FROM | = | $60 | ;loc at start of ROM
| 10 | TO | = | $62 | ;load to start of RAM
| 11 | END | = | $64 | ;loc at end of ROM
| 12 | DRV | = | $BA | ;disk drive number
| 13 | STBAS | = | $AFA5 | ;execute a line
| 14 | PRTSCN | = | $C00C | ;print char to screen
| 15 | PCRA | = | $D501 | ;mem pre-config A reg
| 16 | PCRB | = | $D502 | ;mem pre-config B reg
| 17 | PGSW | = | $D700 | ;int ROM page switch
| 18 | CONFIG | = | $FF00 | ;mem configuration reg
| 19 | LCRA | = | $FF01 | ;mem load-config A reg
| 20 | LCRB | = | $FF02 | ;mem load-config B reg
| 21
8200: A9 92 | 22 | LDA | #RAMLD+LAST;trans loader routine
8202: 85 FA | 23 | | STA | $FA | ; to RAM at $0C00
8204: A2 00 | 24 | | LDX | #$00
8206: BD 14 82 25 | NXTRAN | LDA | BEGIN+3,X
8209: 9D 00 0C 26 | STA | RAMLD,X
820C: E8 | 27 | | INX
820D: E4 FA | 28 | | CPX | $FA
820F: D0 F5 | 29 | | BNE | NXTRAN
8211: 4C 00 0C 30 | BEGIN | JMP | RAMLD | ;jump to loader routine
| 31
| 32 | | ORG | $0C00
| 33
0C00: A9 93 | 34 | RAMLD | LDA | #$93 | ;clear screen
0C02: 20 0C C0 35 | JSR | PRTSCN
0C05: 78 | 36 | | SEI | | ;set the interupt
0C06: A2 00 | 37 | | LDX | #0 | ;clear information indexer
0C08: 8D 01 FF 38 | NXPG | STA | LCRA | ;RAM 0, Int ROM, I/O
0C0B: BD 90 0C 39 | LDA | PGNO,X | ;get first rom page no.
0C0E: 8D 00 D7 40 | STA | PGSW | ;select page at $d700
0C11: 8D 00 D7 41 | STA | PGSW
0C14: BD 8A 0C 42 | LDA | FROMLO,X | ;from rom low byte
0C17: 85 60 | 43 | | STA | FROM
0C19: BD 8B 0C 44 | LDA | FROMHI,X | ;from rom high byte
0C1C: 85 61 | 45 | | STA | FROM+1
0C1E: BD 8C 0C 46 | LDA | TOLO,X | ;to ram low byte
0C21: 85 62 | 47 | | STA | TO
0C23: BD 8D 0C 48 | LDA | TOHI,X | ;to ram high byte
0C26: 85 63 | 49 | | STA | TO+1
0C28: BD 8E 0C 50 | LDA | ENDLO,X | ;end adrs rom low byte
0C2B: 85 64 | 51 | | STA | END
0C2D: BD 8F 0C 52 | LDA | ENDHI,X | ;end adrs rom high byte
0C30: 85 65 | 53 | | STA | END+1
0C32: A0 00 | 54 | | LDY | #$00
0C34: 8D 02 FF 55 | STA | LCRB | ;RAM 0, Int ROM
0C37: B1 60 | 56 | LOOP1 | LDA | (FROM),Y | ;get byte from rom
0C39: 91 62 | 57 | | STA | (TO),Y | ;store byte in ram
0C3B: A5 61 | 58 | | LDA | FROM+1 | ;ck for end lo byte

0C3D: C5 65 | 59 | | CMP | END+1
0C3F: D0 06 | 60 | | BNE | SKIP1 | ;not end, then cont.
0C41: A5 60 | 61 | | LDA | FROM | ;ck for end hi byte
0C43: C5 64 | 62 | | CMP | END
0C45: F0 0E | 63 | | BEQ | SKIP3 | ;if end, ck for nx page
0C47: E6 60 | 64 | SKIP1 | INC | FROM | ;inc from lo
0C49: D0 02 | 65 | | BNE | SKIP2
0C4B: E6 61 | 66 | | INC | FROM+1 | ;inc from hi
0C4D: E6 62 | 67 | SKIP2 | INC | TO | ;inc to lo
0C4F: D0 E6 | 68 | | BNE | LOOP1
0C51: E6 63 | 69 | | INC | TO+1 | ;inc to hi
0C53: D0 E2 | 70 | | BNE | LOOP1 | ;get and store nx byte
0C55: E8 | 71 | SKIP3 | INX
0C56: BD 90 0C 72 | LDA | PGNO,X | ;get next page
0C59: C9 FF | 73 | | CMP | #$FF | ;ck for end of transfer
0C5B: D0 AB | 74 | | BNE | NXPG | ;if not $ff, jmp to nx page
0C5D: A9 00 | 75 | | LDA | #0 | ;switch to
0C5F: 8D 00 FF 76 | STA | CONFIG | ; RAM with all sys ROMs
0C62: 8D 00 D7 77 | STA | PGSW | ; page 0 Int ROM
0C65: 8D 00 D7 78 | STA | PGSW
0C68: A9 3F | 79 | | LDA | #$3F | ;restore pre-conf regs
0C6A: 8D 01 D5 80 | STA | PCRA
0C6D: A9 7F | 81 | | LDA | #$7F
0C6F: 8D 02 D5 82 | STA | PCRB
0C72: A9 08 | 83 | | LDA | #$08 | ;set device 8 as
0C74: 85 BA | 84 | | STA | DRV | ; default drive
0C76: 58 | 85 | | CLI | | ;clr the interrupt
0C77: A2 7D | 86 | | LDX | #<BST-1 | ;lo adrs -1 of start of bas
0C79: A0 0C | 87 | | LDY | #>BST | ;hi adrs of start of bas
0C7B: 4C A5 AF 88 | JMP | STBAS | ;jump execute a line ($AFA5)
| 89
0C7E: 53 59 53 90 | BST | TXT | 'sys7200',00,0d,00,00,00
0C81: 37 32 30 30 00 0D 00 00
0C89: 00
| 91
92 | *** TRANSFER INFORMATION FOR ZED ***
93 | *** $FF INDICATES END OF TRANSFER ***
| 94
0C8A: BF | 95 | FROMLO | HEX | BF
0C8B: 85 | 96 | FROMHI | HEX | 85
0C8C: 01 | 97 | TOLO | HEX | 01
0C8D: 1C | 98 | TOHI | HEX | 1C
0C8E: 14 | 99 | ENDLO | HEX | 14
0C8F: C8 | 100 ENDHI | HEX | C8
0C90: 02 FF | 101 PGNO | HEX | 02,FF
102 LAST

The next loader is basically the same as the previous loader, except it does not use BASIC start. Beginning at line 70 the program will switch in all system ROMs and switch to Page 0 of the Internal ROM. Then clear the interrupt and jump to the beginning of the program at $2000.

2
3 | ********************************
4 | * LOADER FOR MERLIN 128 | *
5 | ********************************
| 6 | *
| 7 | | ORG | $8000
| 8 | *
| 9 | FROM | = | $60
| 10 | TO | = | $62
| 11 | END | = | $64
| 12 | PRTSCN | = | $C00C
| 13 | PGSW | = | $D700
| 14 | CONFIG | = | $FF00
| 15 | LCRA | = | $FF01
| 16 | LCRB | = | $FF02
| 17
8000: A9 6E | 18 | LDA | #RAMLD+LAST
8002: 85 FA | 19 | | STA | $FA
8004: A2 00 | 20 | | LDX | #$00
8006: BD 14 80 21 | NXTRAN | LDA | BEGIN+3,X
8009: 9D 00 0C 22 | STA | RAMLD,X
800C: E8 | 23 | | INX
800D: E4 FA | 24 | | CPX | $FA
800F: D0 F5 | 25 | | BNE | NXTRAN
8011: 4C 00 0C 26 | BEGIN | JMP | RAMLD
| 27
| 28 | | ORG | $0C00
| 29
0C00: A9 93 | 30 | RAMLD | LDA | #$93 | ;clear screen
0C02: 20 0C C0 31 | JSR | PRTSCN
0C05: 78 | 32 | | SEI
0C06: A2 00 | 33 | | LDX | #0 | ;clear information indexer
0C08: BD 6C 0C 34 | LDA | PGNO,X | ;get first rom page no.
0C0B: 8D 01 FF 35 | NXPG | STA | LCRA | ;internal rom w/ io
0C0E: 8D 00 D7 36 | STA | PGSW | ;select page at $d700
0C11: BD 66 0C 37 | LDA | FROMLO,X | ;from rom low byte
0C14: 85 60 | 38 | | STA | FROM
0C16: BD 67 0C 39 | LDA | FROMHI,X | ;from rom high byte
0C19: 85 61 | 40 | | STA | FROM+1
0C1B: BD 68 0C 41 | LDA | TOLO,X | ;to ram low byte
0C1E: 85 62 | 42 | | STA | TO
0C20: BD 69 0C 43 | LDA | TOHI,X | ;to ram high byte
0C23: 85 63 | 44 | | STA | TO+1
0C25: BD 6A 0C 45 | LDA | ENDLO,X | ;end adrs rom low byte
0C28: 85 64 | 46 | | STA | END
0C2A: BD 6B 0C 47 | LDA | ENDHI,X | ;end adrs rom high byte
0C2D: 85 65 | 48 | | STA | END+1
0C2F: A0 00 | 49 | | LDY | #$00
0C31: 8D 02 FF 50 | STA | LCRB | ;all int rom/ram 0
0C34: B1 60 | 51 | LOOP1 | LDA | (FROM),Y | ;get byte from rom
0C36: 91 62 | 52 | | STA | (TO),Y | ;store byte in ram
0C38: A5 61 | 53 | | LDA | FROM+1 | ;ck for end lo byte

0C3A: C5 65 | 54 | | CMP | END+1
0C3C: D0 06 | 55 | | BNE | SKIP1 | ;not end, then cont.
0C3E: A5 60 | 56 | | LDA | FROM | ;ck for end hi byte
0C40: C5 64 | 57 | | CMP | END
0C42: F0 0E | 58 | | BEQ | SKIP3 | ;if end, then ck for nx page
0C44: E6 60 | 59 | SKIP1 | INC | FROM | ;inc from lo
0C46: D0 02 | 60 | | BNE | SKIP2
0C48: E6 61 | 61 | | INC | FROM+1 | ;inc from hi
0C4A: E6 62 | 62 | SKIP2 | INC | TO | ;inc to lo
0C4C: D0 E6 | 63 | | BNE | LOOP1
0C4E: E6 63 | 64 | | INC | TO+1 | ;inc to hi
0C50: D0 E2 | 65 | | BNE | LOOP1 | ;get and store nx byte
0C52: E8 | 66 | SKIP3 | INX
0C53: BD 6C 0C 67 | LDA | PGNO,X | ;get next page
0C56: C9 FF | 68 | | CMP | #$FF | ;ck for end of transfer
0C58: D0 B1 | 69 | | BNE | NXPG | ;if not $ff, jmp to nx page
0C5A: A9 00 | 70 | | LDA | #0 | ;switch to sys ROMs
0C5C: 8D 00 FF 71 | STA | CONFIG
0C5F: 8D 00 D7 72 | STA | PGSW | ;internal ROM pg to 0
0C62: 58 | 73 | | CLI
0C63: 4C 00 1C 74 | JMP | $2000 | ;start Merlin 128
| 75
76 | *** TRANSFER INFORMATION FOR MERLIN ***
77 | *** $FF INDICATES END OF TRANSFER ***
| 78
0C66: 00 | 79 | FROMLO | HEX | 00
0C67: 81 | 80 | FROMHI | HEX | 81
0C68: 40 | 81 | TOLO | HEX | 40
0C69: 1A | 82 | TOHI | HEX | 1A
0C6A: 49 | 83 | ENDLO | HEX | 49
0C6B: F0 | 84 | ENDHI | HEX | F0
0C6C: 01 FF | 85 | PGNO | HEX | 01,FF
| 86 | LAST

The next loader is for VizaWrite Word Processor, you’ll notice it has two loaders. The first one is for the main program which is quite large. It loads from $0B00 to $FEDF and it takes two 32K ROM pages to hold it all. The next loader will load a small amount of code that goes from $0400 to $089A.

### VizaWrite and VizaStar both have a small amount of ROM code that is plugged into the

cartridge port. It works like a dongle, if it’s not there, then the program will crash. I looked

### through the code of the main program and found where the program checks for the cartridge

ROM, changed it to look at Internal ROM instead. So, the last thing the second loader will do before starting the program ($0B1A) is to switch in the page (line 59) that has the ROM code at $8000 (Page 3).

2
3 | **************************************
4 | * VizaWrite LOADER FOR PAGED EPROM *
5 | **************************************
6 | *
7 | ORG | $8500
8 | *
9 | FROM | = | $60
10 | TO | = | $62
11 | END | = | $64
12 | PGSW | = | $D700 | ;page select
13 | CONFIG | = | $FF00
14 | LCRA | = | $FF01
15 | LCRB | = | $FF02
16 | SWAPPER = | $FF5F | ;40,80-col screen swapper
17 | PRIMM | = | $FF7D | ;print text to screen routine
18 | SECLDR | = | $8700 | ;adrs for $0400 ldr
19
8500: A9 06 | 20 | LDA | #$06 | ;RAM 0 & Int ROM,I/O,kernal
8502: 8D 00 FF 21 | STA | CONFIG
8505: A5 D7 | 22 | LDA | $D7 | ;ck for 80-col
8507: D0 03 | 23 | BNE | NO40
8509: 20 5F FF 24 | JSR | SWAPPER | ;swap from 40 to 80-col
850C: 20 7D FF 25 | NO40 | JSR | PRIMM | ;print copyright notice
850F: 93 0D 0D 26 | HEX | 93,0D,0D,0D,0D,0D
8512: 0D 0D 0D
8515: 09 09 09 27 | HEX | 09,09,09,09
8518: 09
8519: 20 20 56 28 | TXT | ' viza'0d,0d,09,09,09,09
851C: 49 5A 41 0D 0D 09 09 09
8524: 09
8525: 53 4F 46 29 | TXT | 'software'0d,0d,09,09,09,09
8528: 54 57 41 52 45 0D 0D 09
8530: 09 09 09
8533: 20 20 31 30 | TXT | ' 128'0d,0d,0d,09,09,09,09
8536: 32 38 0D 0D 0D 09 09 09
853E: 09
853F: 56 49 5A 31 | TXT | 'vizawrite'0d,0d,09,09,09
8542: 41 57 52 49 54 45 0D 0D
854A: 09 09 09
854D: 20 20 20 32 | TXT | ' | by kelvin lacy'0d,0d,0d,09,09
8550: 20 20 42 59 20 4B 45 4C
8558: 56 49 4E 20 4C 41 43 59
8560: 0D 0D 0D 09 09
8565: 20 20 20 33 | TXT | ' | copyright 1985 viza software
ltd.'0d,00
8568: 20 43 4F 50 59 52 49 47
8570: 48 54 20 31 39 38 35 20
8578: 56 49 5A 41 20 53 4F 46 8580: 54 57 41 52 45 20 4C 54 8588: 44 2E 0D 00

858C: A2 00 | 35 | | LDX | #$00 | ;transfer loader to $0400
858E: BD 9A 85 36 | NXTRAN | LDA | BEGIN+3,X
8591: 9D 00 04 37 | STA | $0400,X
8594: E8 | 38 | | INX
8595: D0 F7 | 39 | | BNE | NXTRAN
8597: 4C 00 04 40 | BEGIN | JMP | RAMLD | ;jmp to loader
| 41
| 42 | | ORG | $0400
| 43
0400: 78 | 44 | RAMLD | SEI | | ;set the interrupt
0401: A2 00 | 45 | | LDX | #$00 | ;clear information indexer
0403: BD 6F 04 46 | LDA | PGNO,X | ;get first rom page no.
0406: 8D 01 FF 47 | NXPG | STA | LCRA
0409: 8D 00 D7 48 | STA | PGSW | ;select page at $D700
040C: BD 63 04 49 | LDA | FROMLO,X | ;from rom low byte
040F: 85 60 | 50 | | STA | FROM
0411: BD 65 04 51 | LDA | FROMHI,X | ;from rom high byte
0414: 85 61 | 52 | | STA | FROM+1
0416: BD 67 04 53 | LDA | TOLO,X | ;to ram low byte
0419: 85 62 | 54 | | STA | TO
041B: BD 69 04 55 | LDA | TOHI,X | ;to ram high byte
041E: 85 63 | 56 | | STA | TO+1
0420: BD 6B 04 57 | LDA | ENDLO,X | ;end adrs rom low byte
0423: 85 64 | 58 | | STA | END
0425: BD 6D 04 59 | LDA | ENDHI,X | ;end adrs rom high byte
0428: 85 65 | 60 | | STA | END+1
042A: 8D 02 FF 61 | STA | LCRB
042D: A0 00 | 62 | | LDY | #$00
042F: B1 60 | 63 | LOOP1 | LDA | (FROM),Y | ;get byte from rom
0431: 91 62 | 64 | | STA | (TO),Y | ;store byte in ram
0433: A5 61 | 65 | | LDA | FROM+1 | ;ck for end lo byte
0435: C5 65 | 66 | | CMP | END+1
0437: D0 06 | 67 | | BNE | SKIP1 | ;not end, then cont.
0439: A5 60 | 68 | | LDA | FROM | ;ck for end hi byte
043B: C5 64 | 69 | | CMP | END
043D: F0 0E | 70 | | BEQ | SKIP3 | ;if end, then ck for nx page
043F: E6 60 | 71 | SKIP1 | INC | FROM | ;inc from lo
0441: D0 02 | 72 | | BNE | SKIP2
0443: E6 61 | 73 | | INC | FROM+1 | ;inc from hi
0445: E6 62 | 74 | SKIP2 | INC | TO | ;inc to lo
0447: D0 E6 | 75 | | BNE | LOOP1
0449: E6 63 | 76 | | INC | TO+1 | ;inc to hi
044B: D0 E2 | 77 | | BNE | LOOP1 | ;get and store nx byte
044D: E8 | 78 | SKIP3 | INX
044E: BD 6F 04 79 | LDA | PGNO,X | ;get next page
0451: C9 FF | 80 | | CMP | #$FF | ;ck for end of transfer
0453: D0 B1 | 81 | | BNE | NXPG | ;if not $ff, then jmp to nx
page
0455: A9 06 | 82 | | LDA | #$06 | ;switch cr to RAM 0 & Int ROM
0457: 8D 00 FF 83 | STA | CONFIG
045A: 58 | 84 | | CLI
045B: A9 0A | 85 | | LDA | #$0A | ;switch to page for $0400 ldr
045D: 8D 00 D7 86 | STA | PGSW
0460: 4C 00 87 87 | JMP | SECLDR | ;jmp to $0400 loader
| 88

89 | *** TRANSFER INFORMATION FOR VizaWrite ***
90 | *** $FF INDICATES END OF TRANSFER ***
91
0463: 00 1B | 92 | FROMLO | HEX | 00,1B
0465: 80 8A | 93 | FROMHI | HEX | 80,8A
0467: 00 FE | 94 | TOLO | HEX | 00,FE
0469: 0B 89 | 95 | TOHI | HEX | 0B,89
046B: FD FD | 96 | ENDLO | HEX | FD,FD
046D: FE FE | 97 | ENDHI | HEX | FE,FE
046F: 09 0A FF 98 | PGNO | HEX | 09,0A,FF
| 99

2
3 | **************************************
4 | * VizaWrite LOADER FOR PAGED EPROM *
5 | **************************************
| 6 | *
| 7 | | ORG | $8700
| 8 | *
| 9 | FROM | = | $60
| 10 | TO | = | $62
| 11 | END | = | $64
| 12 | PGSW | = | $D700
| 13
8700: A2 00 | 14 | | LDX | #$00
8702: BD 0E 87 15 | NXTRAN | LDA | BEGIN+3,X
8705: 9D 00 09 16 | STA | $0900,X
8708: E8 | 17 | | INX
8709: D0 F7 | 18 | | BNE | NXTRAN
870B: 4C 00 09 19 | BEGIN | JMP | RAMLD
| 20
| 21 | | ORG | $0900
| 22
0900: A2 00 | 23 | RAMLD | LDX | #$00 | ;clear information indexer
0902: BD 63 09 24 | LDA | PGNO,X | ;get first rom page no.
0905: 8D 00 D7 25 | NXPG | STA | PGSW | ;select page at $d700
0908: 8D 00 D7 26 | STA | PGSW
090B: BD 5D 09 27 | LDA | FROMLO,X | ;from rom low byte
090E: 85 60 | 28 | | STA | FROM
0910: BD 5E 09 29 | LDA | FROMHI,X | ;from rom high byte
0913: 85 61 | 30 | | STA | FROM+1
0915: BD 5F 09 31 | LDA | TOLO,X | ;to ram low byte
0918: 85 62 | 32 | | STA | TO
091A: BD 60 09 33 | LDA | TOHI,X | ;to ram high byte
091D: 85 63 | 34 | | STA | TO+1
091F: BD 61 09 35 | LDA | ENDLO,X | ;end adrs rom low byte
0922: 85 64 | 36 | | STA | END
0924: BD 62 09 37 | LDA | ENDHI,X | ;end adrs rom high byte
0927: 85 65 | 38 | | STA | END+1
0929: A0 00 | 39 | | LDY | #$00
092B: B1 60 | 40 | LOOP1 | LDA | (FROM),Y | ;get byte from rom
092D: 91 62 | 41 | | STA | (TO),Y | ;store byte in ram
092F: A5 61 | 42 | | LDA | FROM+1 | ;ck for end lo byte
0931: C5 65 | 43 | | CMP | END+1
0933: D0 06 | 44 | | BNE | SKIP1 | ;not end, then cont.

0935: A5 60 | 45 | | LDA | FROM | ;ck for end hi byte
0937: C5 64 | 46 | | CMP | END
0939: F0 0E | 47 | | BEQ | SKIP3 | ;if end, then ck for nx page
093B: E6 60 | 48 | SKIP1 | INC | FROM | ;inc from lo
093D: D0 02 | 49 | | BNE | SKIP2
093F: E6 61 | 50 | | INC | FROM+1 | ;inc from hi
0941: E6 62 | 51 | SKIP2 | INC | TO | ;inc to lo
0943: D0 E6 | 52 | | BNE | LOOP1
0945: E6 63 | 53 | | INC | TO+1 | ;inc to hi
0947: D0 E2 | 54 | | BNE | LOOP1 | ;get and store nx byte
0949: E8 | 55 | SKIP3 | INX
094A: BD 63 09 56 | LDA | PGNO,X | ;get next page
094D: C9 FF | 57 | | CMP | #$FF | ;ck for end of transfer
094F: D0 B4 | 58 | | BNE | NXPG | ;if not $ff, jmp to nx page
0951: A9 03 | 59 | | LDA | #$03 | ;switch to page for int-cart
0953: 8D 00 D7 60 | STA | PGSW
0956: 8D 00 D7 61 | STA | PGSW
0959: 78 | 62 | | SEI
095A: 4C 1A 0B 63 | JMP | $0B1A | ;jmp to start pgm
| 64
65 | *** TRANSFER INFORMATION FOR VizaWrite ***
66 | *** $FF INDICATES END OF TRANSFER ***
| 67
095D: 00 | 68 | FROMLO | HEX | 00
095E: 80 | 69 | FROMHI | HEX | 80
095F: 00 | 70 | TOLO | HEX | 00
0960: 04 | 71 | TOHI | HEX | 04
0961: 9A | 72 | ENDLO | HEX | 9A
0962: 84 | 73 | ENDHI | HEX | 84
0963: 0A FF | 74 | PGNO | HEX | 0A,FF
| 75

### The next loader is for a program that runs in C64 mode, Monitor 64. In the first part of

the loader, the code for the monitor is transferred to RAM at $C000. Then the auto-run routine is transferred to $8000. When both programs are in place, a small routine will be placed at $10F0 and then the loader will jump to the routine. All system ROMs are set, page 0 of the Internal ROM is switched in and then the program jumps to Kernal routine GO64.

### When the C128 goes to C64 mode it will start at the reset vector ($FCE2). The first thing

it will do is Set the Interrupt, clear the Stack, Clear the Decimal and then check for “CBM80” at $8004 - $8008. If it finds CBM80, then it will jump to the vector at $8000. At $8009 the code

### will setup C64 mode and stop short of printing the opening screen and printing the READY

prompt. At the very end it will jump to the start of Monitor 64 ($C000).

1
3
4 | MON64 | = | $C000 | ;monitor entry
5 | PRINT | = | $C00C | ;print a char to scrn
6 | PGSW | = | $D700 | ;switch page in Int ROM
7 | CONFIG | = | $FF00 | ;configuration register
8 | GO64 | = | $FF4D | ;128 jmp to 64 mode
9 | INIT | = | $E3BF | ;initialize basic
10 | BASVEC | = | $E453 | ;copies bas vectors
11 | RESTOR | = | $FD15 | ;restores I/O vectors
12 | RAMTAS | = | $FD50 | ;RAM test
13 | IOINIT | = | $FDA3 | ;initialize CIA
14 | CINT | = | $FF5B | ;initialize scrn editor
15
16 | ORG | $8000
17
8000: A9 93 | 18 | LDA | #$93
8002: 20 0C C0 19 | JSR | PRINT | ;clr the screen
8005: A2 05 | 20 | LDX | #$05
8007: BD 57 80 21 | LOOP | LDA | TRAN,X | ;transfer to & from
800A: 95 60 | 22 | STA | $60,X | ; info to variables
800C: CA | 23 | DEX
800D: 10 F8 | 24 | BPL | LOOP
800F: 78 | 25 | SEI
8010: A0 00 | 26 | LDY | #$00
8012: B1 60 | 27 | LOOP1 | LDA | ($60),Y
8014: 91 62 | 28 | STA | ($62),Y
8016: A5 61 | 29 | LDA | $61
8018: C5 65 | 30 | CMP | $65
801A: D0 06 | 31 | BNE | SKIP1
801C: A5 60 | 32 | LDA | $60
801E: C5 64 | 33 | CMP | $64
8020: F0 0E | 34 | BEQ | SKIP3
8022: E6 60 | 35 | SKIP1 | INC | $60
8024: D0 02 | 36 | BNE | SKIP2
8026: E6 61 | 37 | INC | $61
8028: E6 62 | 38 | SKIP2 | INC | $62
802A: D0 E6 | 39 | BNE | LOOP1
802C: E6 63 | 40 | INC | $63
802E: D0 E2 | 41 | BNE | LOOP1
8030: A2 27 | 42 | SKIP3 | LDX | #AUST+END
8032: BD 5D 80 43 | LOOP2 | LDA | TRAN+6,X
8035: 9D 00 80 44 | STA | $8000,X
8038: CA | 45 | DEX
8039: 10 F7 | 46 | BPL | LOOP2
803B: A2 0D | 47 | LDX | #$0D
803D: BD 49 80 48 | LOOP3 | LDA | RAMST,X
8040: 9D F0 10 49 | STA | $10F0,X
8043: CA | 50 | DEX
8044: 10 F7 | 51 | BPL | LOOP3
8046: 4C F0 10 52 | JMP | $10F0
53

8049: A9 00 | 54 | RAMST | LDA | #0
804B: 8D 00 FF 55 | STA | CONFIG
804E: 8D 00 D7 56 | STA | PGSW
8051: 8D 00 D7 57 | STA | PGSW
8054: 4C 4D FF 58 | JMP | GO64
| 59
8057: 3E F0 | 60 | TRAN | DA | $F03E | ;from in ROM
8059: 00 C0 | 61 | | DA | MON64 | ;to in RAM
805B: FD FE | 62 | | DA | $FEFD | ;end in ROM
| 63
64 | **********************************
65 | * this is the auto-start routine *
66 | * that will start C64 monitor | *
67 | **********************************
| 68
| 69 | | ORG | $8000
| 70
8000: 09 80 | 71 | AUST | DA | $8009
8002: 09 80 | 72 | | DA | $8009
| 73
8004: C3 C2 CD 74 | TXT | "cbm" | ;bit 7 is set on cbm
8007: 38 30 | 75 | | TXT | '80'
| 76
8009: A2 05 | 77 | | LDX | #$05
800B: 8E 08 80 78 | STX | $8008 | ;disable auto-start
800E: 8E 16 D0 79 | STX | $D016
8011: 20 A3 FD 80 | JSR | IOINIT
8014: 20 50 FD 81 | JSR | RAMTAS
8017: 20 15 FD 82 | JSR | RESTOR
801A: 20 5B FF 83 | JSR | CINT
801D: 58 | 84 | | CLI
801E: 20 53 E4 85 | JSR | BASVEC
8021: 20 BF E3 86 | JSR | INIT
8024: 4C 00 C0 87 | JMP | MON64
| 88 | END

The next loader program is used for all the Maverick programs. The C64 auto-start routine for the C64 is at the end of the program code.

2
3 | ********************************
4 | * LOADER FOR MAVERICK PGMS | *
5 | ********************************
6 | *
7 | | ORG | $9100
8 | *
9 | FROM | = | $60
10 | TO | = | $62

| 11 | END | = | $64
| 12 | PRTSCN | = | $C00C
| 13 | PGSW | = | $D700
| 14 | CONFIG | = | $FF00
| 15 | GO64 | = | $FF4D
| 16
9100: A9 71 | 17 | LDA | #RAMLD+LAST
9102: 85 FA | 18 | | STA | $FA
9104: A2 00 | 19 | | LDX | #$00
9106: BD 14 91 20 | NXTRAN | LDA | BEGIN+3,X
9109: 9D 00 0C 21 | STA | RAMLD,X
910C: E8 | 22 | | INX
910D: E4 FA | 23 | | CPX | $FA
910F: D0 F5 | 24 | | BNE | NXTRAN
9111: 4C 00 0C 25 | BEGIN | JMP | RAMLD
| 26
| 27 | | ORG | $0C00
| 28
0C00: A9 93 | 29 | RAMLD | LDA | #$93 | ;clear screen
0C02: 20 0C C0 30 | JSR | PRTSCN
0C05: 78 | 31 | | SEI
0C06: A2 00 | 32 | | LDX | #0 | ;clear information indexer
0C08: BD 6F 0C 33 | LDA | PGNO,X | ;get first rom page no.
0C0B: 8D 00 D7 34 | NXPG | STA | PGSW | ;select page at $d700
0C0E: 8D 00 D7 35 | STA | PGSW
0C11: BD 69 0C 36 | LDA | FROMLO,X | ;from rom low byte
0C14: 85 60 | 37 | | STA | FROM
0C16: BD 6A 0C 38 | LDA | FROMHI,X | ;from rom high byte
0C19: 85 61 | 39 | | STA | FROM+1
0C1B: BD 6B 0C 40 | LDA | TOLO,X | ;to ram low byte
0C1E: 85 62 | 41 | | STA | TO
0C20: BD 6C 0C 42 | LDA | TOHI,X | ;to ram high byte
0C23: 85 63 | 43 | | STA | TO+1
0C25: BD 6D 0C 44 | LDA | ENDLO,X | ;end adrs rom low byte
0C28: 85 64 | 45 | | STA | END
0C2A: BD 6E 0C 46 | LDA | ENDHI,X | ;end adrs rom high byte
0C2D: 85 65 | 47 | | STA | END+1
0C2F: 8D 02 FF 48 | STA | $FF02
0C32: A0 00 | 49 | | LDY | #$00
0C34: B1 60 | 50 | H0C24 | LDA | (FROM),Y | ;get byte from rom
0C36: 91 62 | 51 | | STA | (TO),Y | ;store byte in ram
0C38: A5 61 | 52 | | LDA | FROM+1 | ;ck for end lo byte
0C3A: C5 65 | 53 | | CMP | END+1
0C3C: D0 06 | 54 | | BNE | H0C3B | ;not end, then cont.
0C3E: A5 60 | 55 | | LDA | FROM | ;ck for end hi byte
0C40: C5 64 | 56 | | CMP | END
0C42: F0 0E | 57 | | BEQ | H0C49 | ;if end, then ck for nx page
0C44: E6 60 | 58 | H0C3B | INC | FROM | ;inc from lo
0C46: D0 02 | 59 | | BNE | H0C41
0C48: E6 61 | 60 | | INC | FROM+1 | ;inc from hi
0C4A: E6 62 | 61 | H0C41 | INC | TO | ;inc to lo
0C4C: D0 E6 | 62 | | BNE | H0C24
0C4E: E6 63 | 63 | | INC | TO+1 | ;inc to hi
0C50: D0 E2 | 64 | | BNE | H0C24 | ;get and store nx byte

0C52: E8 | 65 | H0C49 | INX
0C53: BD 6F 0C 66 | LDA | PGNO,X | ;get next page
0C56: C9 FF | 67 | CMP | #$FF | ;ck for end of transfer
0C58: D0 B1 | 68 | BNE | NXPG | ;if not $ff, jmp to nx page
0C5A: A9 00 | 69 | LDA | #0 | ;switch to page 0
0C5C: 8D 00 FF 70 | STA | CONFIG
0C5F: 8D 00 D7 71 | STA | PGSW
0C62: 8D 00 D7 72 | STA | PGSW
0C65: 58 | 73 | CLI
0C66: 4C 4D FF 74 | JMP | GO64
75
76 | *** TRANSFER INFORMATION FOR MAVERICK ***
77 | *** $FF INDICATES END OF TRANSFER ***
78
0C69: EC | 79 | FROMLO | HEX | EC
0C6A: 9C | 80 | FROMHI | HEX | 9C
0C6B: 00 | 81 | TOLO | HEX | 00
0C6C: 4F | 82 | TOHI | HEX | 4F
0C6D: F4 | 83 | ENDLO | HEX | F4
0C6E: CD | 84 | ENDHI | HEX | CD
0C6F: 05 FF | 85 | PGNO | HEX | 05,FF
86 | LAST
87

The Maverick program is transferred to memory at $4F00 (see line 81 and 82 above), the end of the program is at $7EFF. The following program will setup C64 mode and transfer the program to its proper location and start it.

The end of all the Maverick programs in Internal ROM is at $8008. The following at $8000 will

### auto-start the C64: $8000 00 7F 00 7F C3 C2 CD 38 30

$7F00
$7F00

### CBM80

### When the beginning of C64 code sees the CBM80 it will jump to $7F00 and run the following code. It will move the program from $4F00-$7EFF to $0800-$37FF and start the program at

$0800.

1
2 | *****************************
3 | * maverick loader and start *
4 | *****************************
5
6 | MAVST | = | $0800 | ;maverick entry
7 | INIT | = | $E3BF | ;initialize basic

8 | BASVEC | = | $E453 | ;copies basic vectors
9 | RESTOR | = | $FD15 | ;restores I/O vectors
10 | RAMTAS | = | $FD50 | ;RAM test
11 | IOINIT | = | $FDA3 | ;initialize CIA
12 | CINT | = | $FF5B | ;initialize scrn editor
13
14 | ORG | $7F00
15
16 | ******************
17 | * setup C64 mode *
18 | ******************
19
7F00: A2 05 | 20 | LDX | #$05
7F02: 8E 08 80 21 | STX | $8008 | ;disable auto-start
7F05: 8E 16 D0 22 | STX | $D016
7F08: 20 A3 FD 23 | JSR | IOINIT
7F0B: 20 50 FD 24 | JSR | RAMTAS
7F0E: 20 15 FD 25 | JSR | RESTOR
7F11: 20 5B FF 26 | JSR | CINT
7F14: 58 | 27 | CLI
7F15: 20 53 E4 28 | JSR | BASVEC
7F18: 20 BF E3 29 | JSR | INIT
30
31 | *****************************
32 | * transfer maverick pgm to *
33 | * proper location & start | *
34 | * from $4F00-$7EFF to $0800 *
35 | *****************************
36
7F1B: A9 00 | 37 | LDA | #$00
7F1D: 85 FB | 38 | STA | $FB
7F1F: 85 FD | 39 | STA | $FD
7F21: AA | 40 | TAX
7F22: A9 54 | 41 | LDA | #$4F
7F24: 85 FC | 42 | STA | $FC
7F26: A9 08 | 43 | LDA | #$08
7F28: 85 FE | 44 | STA | $FE
7F2A: A0 00 | 45 | LDY | #$00
7F2C: B1 FB | 46 | LOOP | LDA | ($FB),Y
7F2E: 91 FD | 47 | STA | ($FD),Y
7F30: 8A | 48 | TXA | ;clean up as you go
7F31: 91 FB | 49 | STA | ($FB),Y
7F33: C8 | 50 | INY
7F34: D0 F6 | 51 | BNE | LOOP
7F36: E6 FC | 52 | INC | $FC
7F38: E6 FE | 53 | INC | $FE
7F3A: A5 FC | 54 | LDA | $FC
7F3C: C9 7F | 55 | CMP | #$7F
7F3E: D0 EC | 56 | BNE | LOOP
7F40: A9 08 | 57 | LDA | #$08 | ;set drv 8 as default
7F42: 85 BA | 58 | STA | $BA
7F44: 4C 00 08 59 | JMP | MAVST | ;jmp to pgm start
60

# THE C64 CARTRIDGE

### The C64 Cartridge will have the same memory space available as the C128 Internal ROM

Adapter, but you can only access 16K bytes at a time ($8000 to $BFFF). Then you will have to switch to another page for more data or you can start your program.

### The cartridge can be used in several different ways, 8K ROM cartridge programs, 16K ROM

cartridge programs, any size programs that run in RAM. Also you can switch the cartridge off and go to Basic, all under software control.

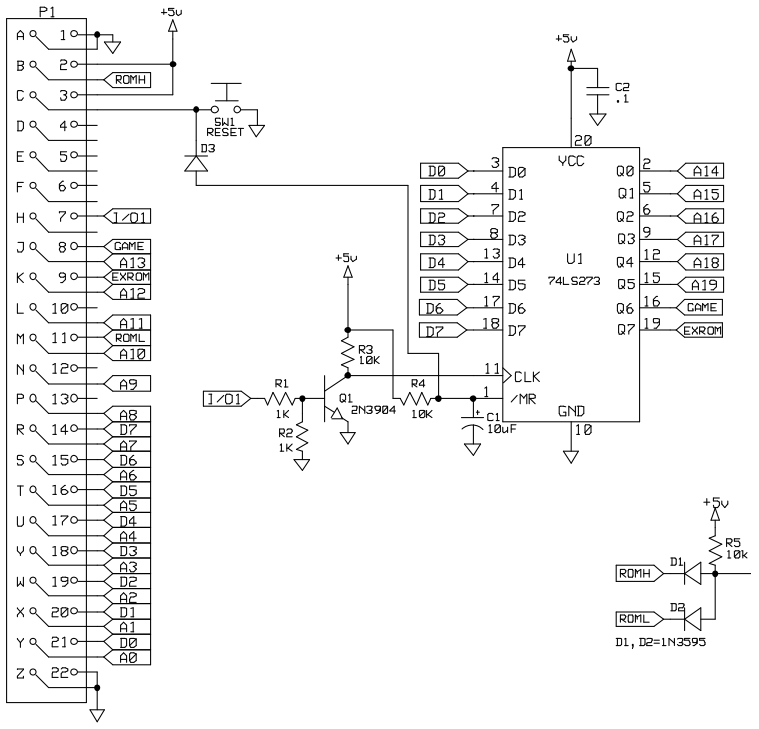
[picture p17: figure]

### Figure 3

In Figure 3 above you’ll notice a 74LS273 (Octal D Flip-Flop) is used to control the extra address lines of the high capacity EPROMs. The 74LS273 is a high-speed 8-Bit Register. The register consists of eight D-Type Flip-Flops with a Common Clock and an asynchronous active

### LOW Master Reset. It works the same as the C128 Internal ROM Adapter, except it has two

extra control lines that are used to control the GAME and EXROM lines on the C64. Bit 6 will control GAME and Bit 7 will control EXROM.

### Here is how it looks with a 27010 (2 MEG EPROM):

Pg HEX | A16 A15 A14
Page 00 | 0 | 0 | 0 | 16K x 8
Page 01 | 0 | 0 | 1 | 16K x 8
Page 02 | 0 | 1 | 0 | 16K x 8
Page 03 | 0 | 1 | 1 | 16K x 8
Page 04 | 1 | 0 | 0 | 16K x 8
Page 05 | 1 | 0 | 1 | 16K x 8
Page 06 | 1 | 1 | 0 | 16K x 8
Page 07 | 1 | 1 | 1 | 16K x 8
Total | 128K x 8

### Here is how it looks with a 27020 (4 MEG EPROM):

Pg HEX | A17 A16 A15 A14
Page 00 | 0 | 0 | 0 | 0 | 16K x 8
Page 01 | 0 | 0 | 0 | 1 | 16K x 8
Page 02 | 0 | 0 | 1 | 0 | 16K x 8
Page 03 | 0 | 0 | 1 | 1 | 16K x 8
Page 04 | 0 | 1 | 0 | 0 | 16K x 8
Page 05 | 0 | 1 | 0 | 1 | 16K x 8
Page 06 | 0 | 1 | 1 | 0 | 16K x 8
Page 07 | 0 | 1 | 1 | 1 | 16K x 8
Page 08 | 1 | 0 | 0 | 0 | 16K x 8
Page 09 | 1 | 0 | 0 | 1 | 16K x 8
Page 0A | 1 | 0 | 1 | 0 | 16K x 8
Page 0B | 1 | 0 | 1 | 1 | 16K x 8
Page 0C | 1 | 1 | 0 | 0 | 16K x 8
Page 0D | 1 | 1 | 0 | 1 | 16K x 8
Page 0E | 1 | 1 | 1 | 0 | 16K x 8
Page 0F | 1 | 1 | 1 | 1 | 16K x 8
Total | | | | | 256K x 8

### Here is how it looks with a 27040 (8 MEG EPROM):

Pg HEX | A18 A17 A16 A15 A14
Page 00 | 0 | 0 | 0 | 0 | 0 | 16K x 8
Page 01 | 0 | 0 | 0 | 0 | 1 | 16K x 8
Page 02 | 0 | 0 | 0 | 1 | 0 | 16K x 8
Page 03 | 0 | 0 | 0 | 1 | 1 | 16K x 8
Page 04 | 0 | 0 | 1 | 0 | 0 | 16K x 8
Page 05 | 0 | 0 | 1 | 0 | 1 | 16K x 8
Page 06 | 0 | 0 | 1 | 1 | 0 | 16K x 8
Page 07 | 0 | 0 | 1 | 1 | 1 | 16K x 8
Page 08 | 0 | 1 | 0 | 0 | 0 | 16K x 8
Page 09 | 0 | 1 | 0 | 0 | 1 | 16K x 8
Page 0A | 0 | 1 | 0 | 1 | 0 | 16K x 8
Page 0B | 0 | 1 | 0 | 1 | 1 | 16K x 8
Page 0C | 0 | 1 | 1 | 0 | 0 | 16K x 8
Page 0D | 0 | 1 | 1 | 0 | 1 | 16K x 8
Page 0E | 0 | 1 | 1 | 1 | 0 | 16K x 8
Page 0F | 0 | 1 | 1 | 1 | 1 | 16K x 8
Page 10 | 1 | 0 | 0 | 0 | 0 | 16K x 8
Page 11 | 1 | 0 | 0 | 0 | 1 | 16K x 8
Page 12 | 1 | 0 | 0 | 1 | 0 | 16K x 8
Page 13 | 1 | 0 | 0 | 1 | 1 | 16K x 8
Page 14 | 1 | 0 | 1 | 0 | 0 | 16K x 8
Page 15 | 1 | 0 | 1 | 0 | 1 | 16K x 8
Page 16 | 1 | 0 | 1 | 1 | 0 | 16K x 8
Page 17 | 1 | 0 | 1 | 1 | 1 | 16K x 8
Page 18 | 1 | 1 | 0 | 0 | 0 | 16K x 8
Page 19 | 1 | 1 | 0 | 0 | 1 | 16K x 8
Page 1A | 1 | 1 | 0 | 1 | 0 | 16K x 8
Page 1B | 1 | 1 | 0 | 1 | 1 | 16K x 8
Page 1C | 1 | 1 | 1 | 0 | 0 | 16K x 8
Page 1D | 1 | 1 | 1 | 0 | 1 | 16K x 8
Page 1E | 1 | 1 | 1 | 1 | 0 | 16K x 8
Page 1F | 1 | 1 | 1 | 1 | 1 | 16K x 8
Total | | | | | | 512K x 8

### Here is how it looks with a 27080 (8 MEG EPROM):

Pg HEX | A19 A18 A17 A16 A15 A14
Page 00 | 0 | 0 | 0 | 0 | 0 | 0 | 16K x 8
Page 01 | 0 | 0 | 0 | 0 | 0 | 1 | 16K x 8
Page 02 | 0 | 0 | 0 | 0 | 1 | 0 | 16K x 8
Page 03 | 0 | 0 | 0 | 0 | 1 | 1 | 16K x 8
Page 04 | 0 | 0 | 0 | 1 | 0 | 0 | 16K x 8
Page 05 | 0 | 0 | 0 | 1 | 0 | 1 | 16K x 8
Page 06 | 0 | 0 | 0 | 1 | 1 | 0 | 16K x 8
Page 07 | 0 | 0 | 0 | 1 | 1 | 1 | 16K x 8
Page 08 | 0 | 0 | 1 | 0 | 0 | 0 | 16K x 8
Page 09 | 0 | 0 | 1 | 0 | 0 | 1 | 16K x 8
Page 0A | 0 | 0 | 1 | 0 | 1 | 0 | 16K x 8
Page 0B | 0 | 0 | 1 | 0 | 1 | 1 | 16K x 8
Page 0C | 0 | 0 | 1 | 1 | 0 | 0 | 16K x 8
Page 0D | 0 | 0 | 1 | 1 | 0 | 1 | 16K x 8
Page 0E | 0 | 0 | 1 | 1 | 1 | 0 | 16K x 8
Page 0F | 0 | 0 | 1 | 1 | 1 | 1 | 16K x 8
Page 10 | 0 | 1 | 0 | 0 | 0 | 0 | 16K x 8
Page 11 | 0 | 1 | 0 | 0 | 0 | 1 | 16K x 8
Page 12 | 0 | 1 | 0 | 0 | 1 | 0 | 16K x 8
Page 13 | 0 | 1 | 0 | 0 | 1 | 1 | 16K x 8
Page 14 | 0 | 1 | 0 | 1 | 0 | 0 | 16K x 8
Page 15 | 0 | 1 | 0 | 1 | 0 | 1 | 16K x 8
Page 16 | 0 | 1 | 0 | 1 | 1 | 0 | 16K x 8
Page 17 | 0 | 1 | 0 | 1 | 1 | 1 | 16K x 8
Page 18 | 0 | 1 | 1 | 0 | 0 | 0 | 16K x 8
Page 19 | 0 | 1 | 1 | 0 | 0 | 1 | 16K x 8
Page 1A | 0 | 1 | 1 | 0 | 1 | 0 | 16K x 8
Page 1B | 0 | 1 | 1 | 0 | 1 | 1 | 16K x 8
Page 1C | 0 | 1 | 1 | 1 | 0 | 0 | 16K x 8
Page 1D | 0 | 1 | 1 | 1 | 0 | 1 | 16K x 8
Page 1E | 0 | 1 | 1 | 1 | 1 | 0 | 16K x 8
Page 1F | 0 | 1 | 1 | 1 | 1 | 1 | 16K x 8
Page 20 | 1 | 0 | 0 | 0 | 0 | 0 | 16K x 8
Page 21 | 1 | 0 | 0 | 0 | 0 | 1 | 16K x 8
Page 22 | 1 | 0 | 0 | 0 | 1 | 0 | 16K x 8
Page 23 | 1 | 0 | 0 | 0 | 1 | 1 | 16K x 8
Page 24 | 1 | 0 | 0 | 1 | 0 | 0 | 16K x 8
Page 25 | 1 | 0 | 0 | 1 | 0 | 1 | 16K x 8
Page 26 | 1 | 0 | 0 | 1 | 1 | 0 | 16K x 8
Page 27 | 1 | 0 | 0 | 1 | 1 | 1 | 16K x 8

Pg HEX | A19 A18 A17 A16 A15 A14
Page 28 | 1 | 0 | 1 | 0 | 0 | 0 | 16K x 8
Page 29 | 1 | 0 | 1 | 0 | 0 | 1 | 16K x 8
Page 2A | 1 | 0 | 1 | 0 | 1 | 0 | 16K x 8
Page 2B | 1 | 0 | 1 | 0 | 1 | 1 | 16K x 8
Page 2C | 1 | 0 | 1 | 1 | 0 | 0 | 16K x 8
Page 2D | 1 | 0 | 1 | 1 | 0 | 1 | 16K x 8
Page 2E | 1 | 0 | 1 | 1 | 1 | 0 | 16K x 8
Page 2F | 1 | 0 | 1 | 1 | 1 | 1 | 16K x 8
Page 30 | 1 | 1 | 0 | 0 | 0 | 0 | 16K x 8
Page 31 | 1 | 1 | 0 | 0 | 0 | 1 | 16K x 8
Page 32 | 1 | 1 | 0 | 0 | 1 | 0 | 16K x 8
Page 33 | 1 | 1 | 0 | 0 | 1 | 1 | 16K x 8
Page 34 | 1 | 1 | 0 | 1 | 0 | 0 | 16K x 8
Page 35 | 1 | 1 | 0 | 1 | 0 | 1 | 16K x 8
Page 36 | 1 | 1 | 0 | 1 | 1 | 0 | 16K x 8
Page 37 | 1 | 1 | 0 | 1 | 1 | 1 | 16K x 8
Page 38 | 1 | 1 | 1 | 0 | 0 | 0 | 16K x 8
Page 39 | 1 | 1 | 1 | 0 | 0 | 1 | 16K x 8
Page 3A | 1 | 1 | 1 | 0 | 1 | 0 | 16K x 8
Page 3B | 1 | 1 | 1 | 0 | 1 | 1 | 16K x 8
Page 3C | 1 | 1 | 1 | 1 | 0 | 0 | 16K x 8
Page 3D | 1 | 1 | 1 | 1 | 0 | 1 | 16K x 8
Page 3E | 1 | 1 | 1 | 1 | 1 | 0 | 16K x 8
Page 3F | 1 | 1 | 1 | 1 | 1 | 1 | 16K x 8
Total | | | | | | | 1024K x 8

### Page Bit 6 Bit 7

00 | 0 | 0 | GAME & EXROM pulled low (access pg #0 to pg #63)
40 | 0 | 1 | GAME is high & EXROM is low
80 | 1 | 0 | GAME is low & EXROM is high
C0 | 1 | 1 | GAME is high & EXROM is high (turn off cartridge)

When Bits 6 and 7 are high, then the cartridge is turned off. Selecting page number $C0 will turn off the cartridge. In the Menu the STOP key will turn off the cartridge and send you to BASIC. Also when you load and run a program that runs in RAM, you will have to turn the cartridge off before the program is started.

The following menu program will work on a C64 or C128 in the C64 mode. The first menu will access 26 programs, the second menu will access 26 programs and the third menu will access 26 programs. You probably will not need the third menu. The stop key will turn off the cartridge and exit to BASIC.

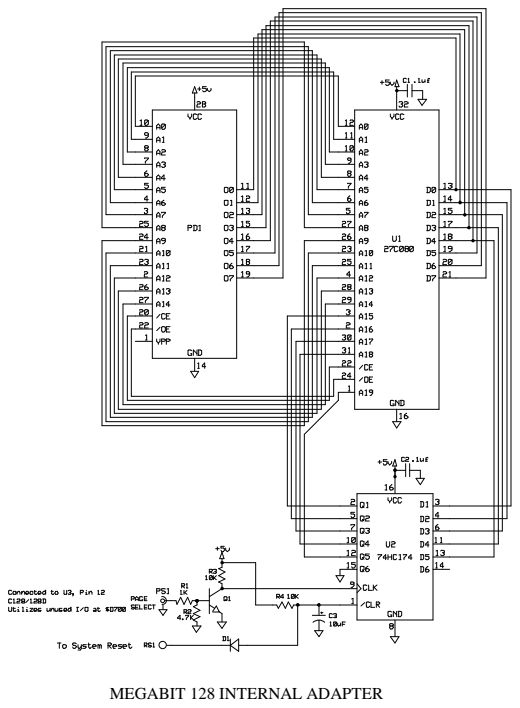
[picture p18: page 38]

MEGABIT 128 INTERNAL ADAPTER

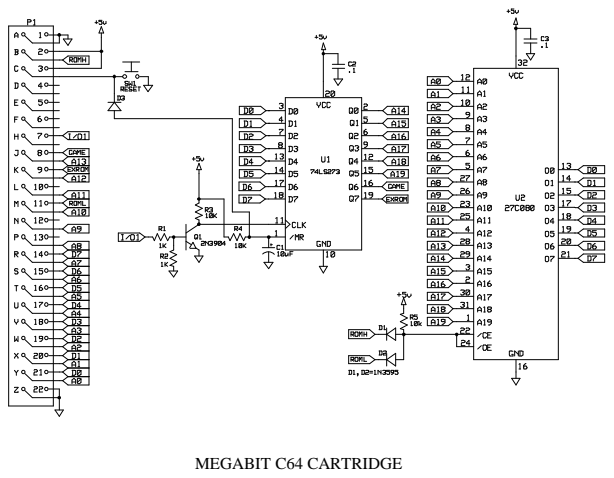
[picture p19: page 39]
MEGABIT C64 CARTRIDGE

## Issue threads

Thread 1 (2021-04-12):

Part List / Footprints.

dabonetn, 2021-04-12:
I'm about to order some of these, and would like to know the footprints for the ic's and other components.

Also, on the panelized version of the gerbers, it appears to only have one copy of the board on the panel.

JDet-74, 2021-04-12:
> I'm about to order some of these, and would like to know the footprints for the ic's and other components.

the BOM is in the [manual PDF File](https://github.com/JDet-74/C128_U36_adapter/blob/main/C128_U36_adapter_MANUAL.pdf).
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

> Also, on the panelized version of the gerbers, it appears to only have one copy of the board on the panel.

that's O.K.
If you order from JLCPCB, it will show you just one adapter PCBs instead of eight adapters.
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
My order looked like that
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
I created the panel with the EasyEDA panalizing tool - so JLCPCB will notice the information file in the GERBER files and will create a panel.

dabonetn, 2021-04-12:
I did the same thing you did this year, and built a clone of the original.
Mine actually works… but only in fast mode… and only some times….

My original Megabit 128 is that circuit exactly, and works everytime. It has a 3904 transistor.

My megabit came with a 27c040 image. The menus are the same, but it’s missing a few of the bigger programs. Would you like a copy of that image also?
(512K – Help key to enable)

Thank you very much for releasing your project. Would you happen to be interested in a internal swiftlink compatible wifi modem for your 128?

I make swiftlink compatible Carts and Internal models for the 64/128.

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

JDet-74, 2021-04-13:
> I did the same thing you did this year, and built a clone of the original.
Mine actually works… but only in fast mode… and only some times….

Hmmm ... strange world ;)
I could not figure it out with the original circuit.

> My original Megabit 128 is that circuit exactly, and works everytime. It has a 3904 transistor.

Thank you for this information. This transistor (2N3904) is fast enough - I tried a SMD clone of a BC547 and this one was too slow. I tested it with 1 MHz switching frequency and that was to fast. So I tried logic gates and recognized the GLITCH on Pin12 of U3. Unfortunately I cannot find a SMD Version of the 2N3904.

> My megabit came with a 27c040 image. The menus are the same, but it’s missing a few of the bigger programs. Would you like a copy of that image also? (512K – Help key to enable)

Of course ... if you send me the image file (kernelpanic_74[at]yahoo.de), I will provide it in this repository.

> Thank you very much for releasing your project.

You are welcome ;) for the retro community.

> Would you happen to be interested in a internal swiftlink compatible wifi modem for your 128?

Why not? You mean that? [Link232-Wifi](https://github.com/dabonetn/Link232-Wifi.git)
I will have a look at your project and maybe order some PCBs with my next JLCPCB order.
**Do you sell some built ones? If YES, how much?**

JDet-74, 2021-04-13:
Sorry ... unfortunately I closed this issue :) so stupid ...

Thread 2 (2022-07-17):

EasyEDA or KiCad etc. project?

mjcargill, 2022-07-17:
Hi,

I'd like to build a couple of these and wondered if you had the project/schematics available so that I can generate the pick and place files to get them built and the components done via an SMT service?

Many thanks,

mjcargill, 2022-07-18:
Hi,

Not all services will do both sides (there are some but expensive), but I can get most of it done (topside) and only have one chip to solder underneath – save me a bit of time 😊

If you could publish the Eagle files, that would be amazing!

Many thanks,

JDet-74, 2022-07-19:
Eagel files are published ... use them ... improve them ... have fun :)

mjcargill, 2022-07-22:
Thanks!  I will! :-)

mjcargill, 2022-10-11:
Hi,

Not all services will do both sides (there are some but expensive), but I can get most of it done (topside) and only have one chip to solder underneath – save me a bit of time 😊

If you could publish the Eagle files, that would be amazing!

Many thanks,

Mark.

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

Closed 2022-07-23.

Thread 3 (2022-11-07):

BOM/CPL files to oder pre-assembled PCBs from JLCPCB

Marko-fin, 2022-11-07:
Would like to oder pre-assembled PCBS, but for that would need file that could be opened in EasyEDA and export BOM/CPL or have those files separately avaiable to upload with PANEL gerber files.

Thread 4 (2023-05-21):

Issue with the bin file

XumetBDN, 2023-05-21:
Hi! I did some boards and worked with some issues. I burned the bin file in some different 27c010 eproms. After press HELP the menu appears and only the first programs worked. None of the 2nd or 3th page worked.  I.E. the servant, basic8 etc doesn't work. Just a reboot with any success. Is there any special way to buy the eprom?

Marko-fin, 2023-10-31:
Hi, I read from Forum64 where it is discussed, that bin file does not fit in 27c010.

https://www.forum64.de/index.php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
"Ein 27C010 funktioniert definitiv nicht für das "Megabit HELP"-ROM, das hat eine Dateigröße von 1 MByte und passt daher nicht in ein 27C010."

Basically I see many people are using 8Mbt 27C080 eproms.

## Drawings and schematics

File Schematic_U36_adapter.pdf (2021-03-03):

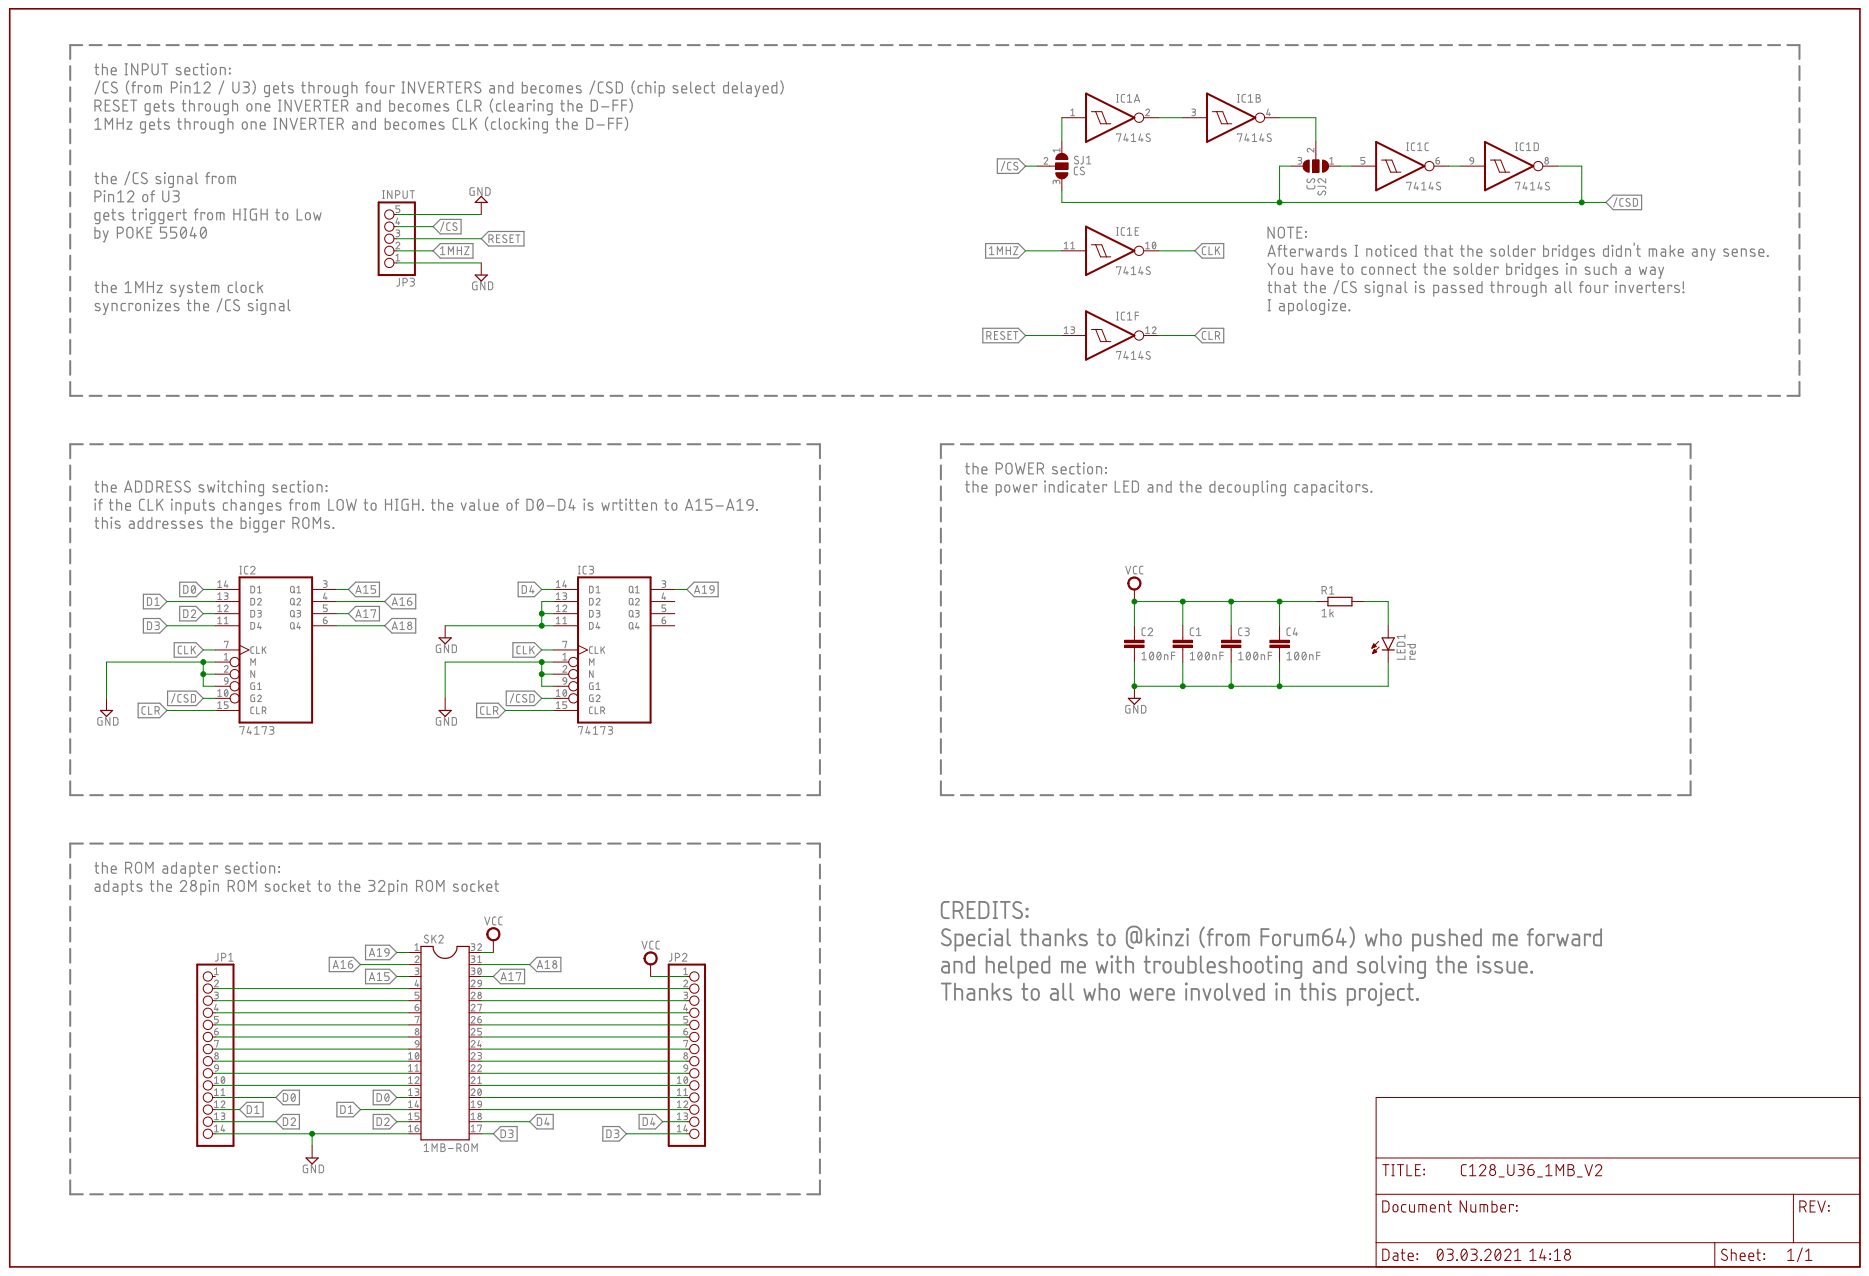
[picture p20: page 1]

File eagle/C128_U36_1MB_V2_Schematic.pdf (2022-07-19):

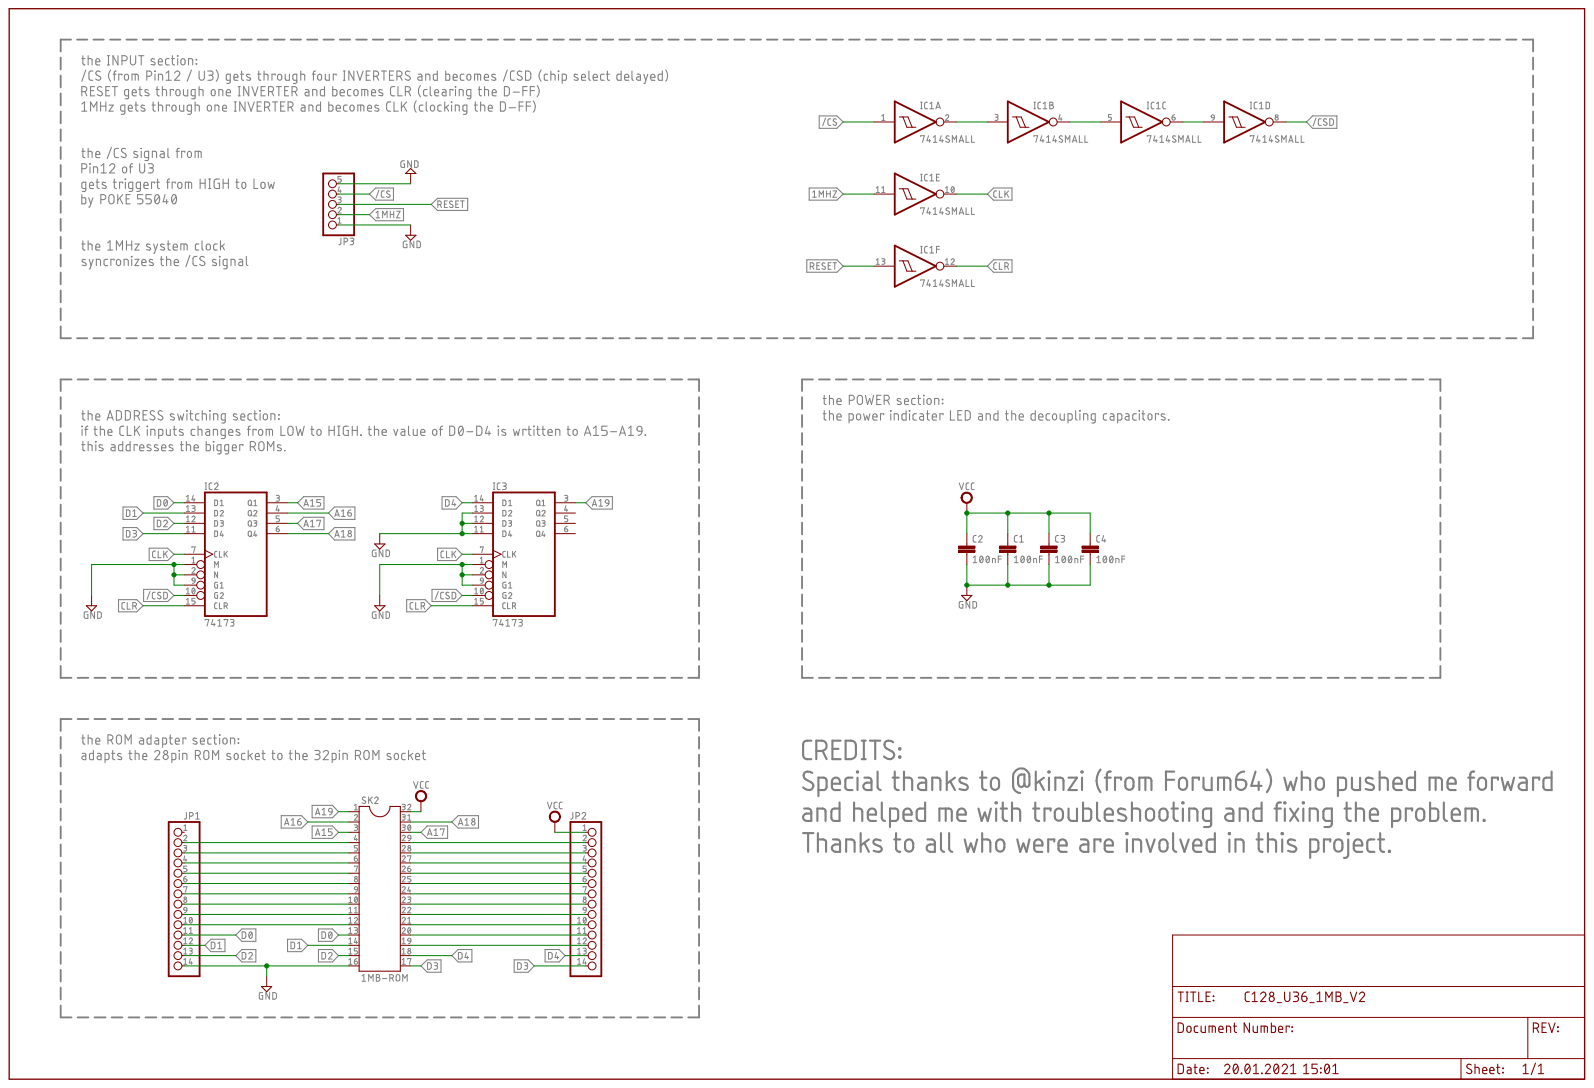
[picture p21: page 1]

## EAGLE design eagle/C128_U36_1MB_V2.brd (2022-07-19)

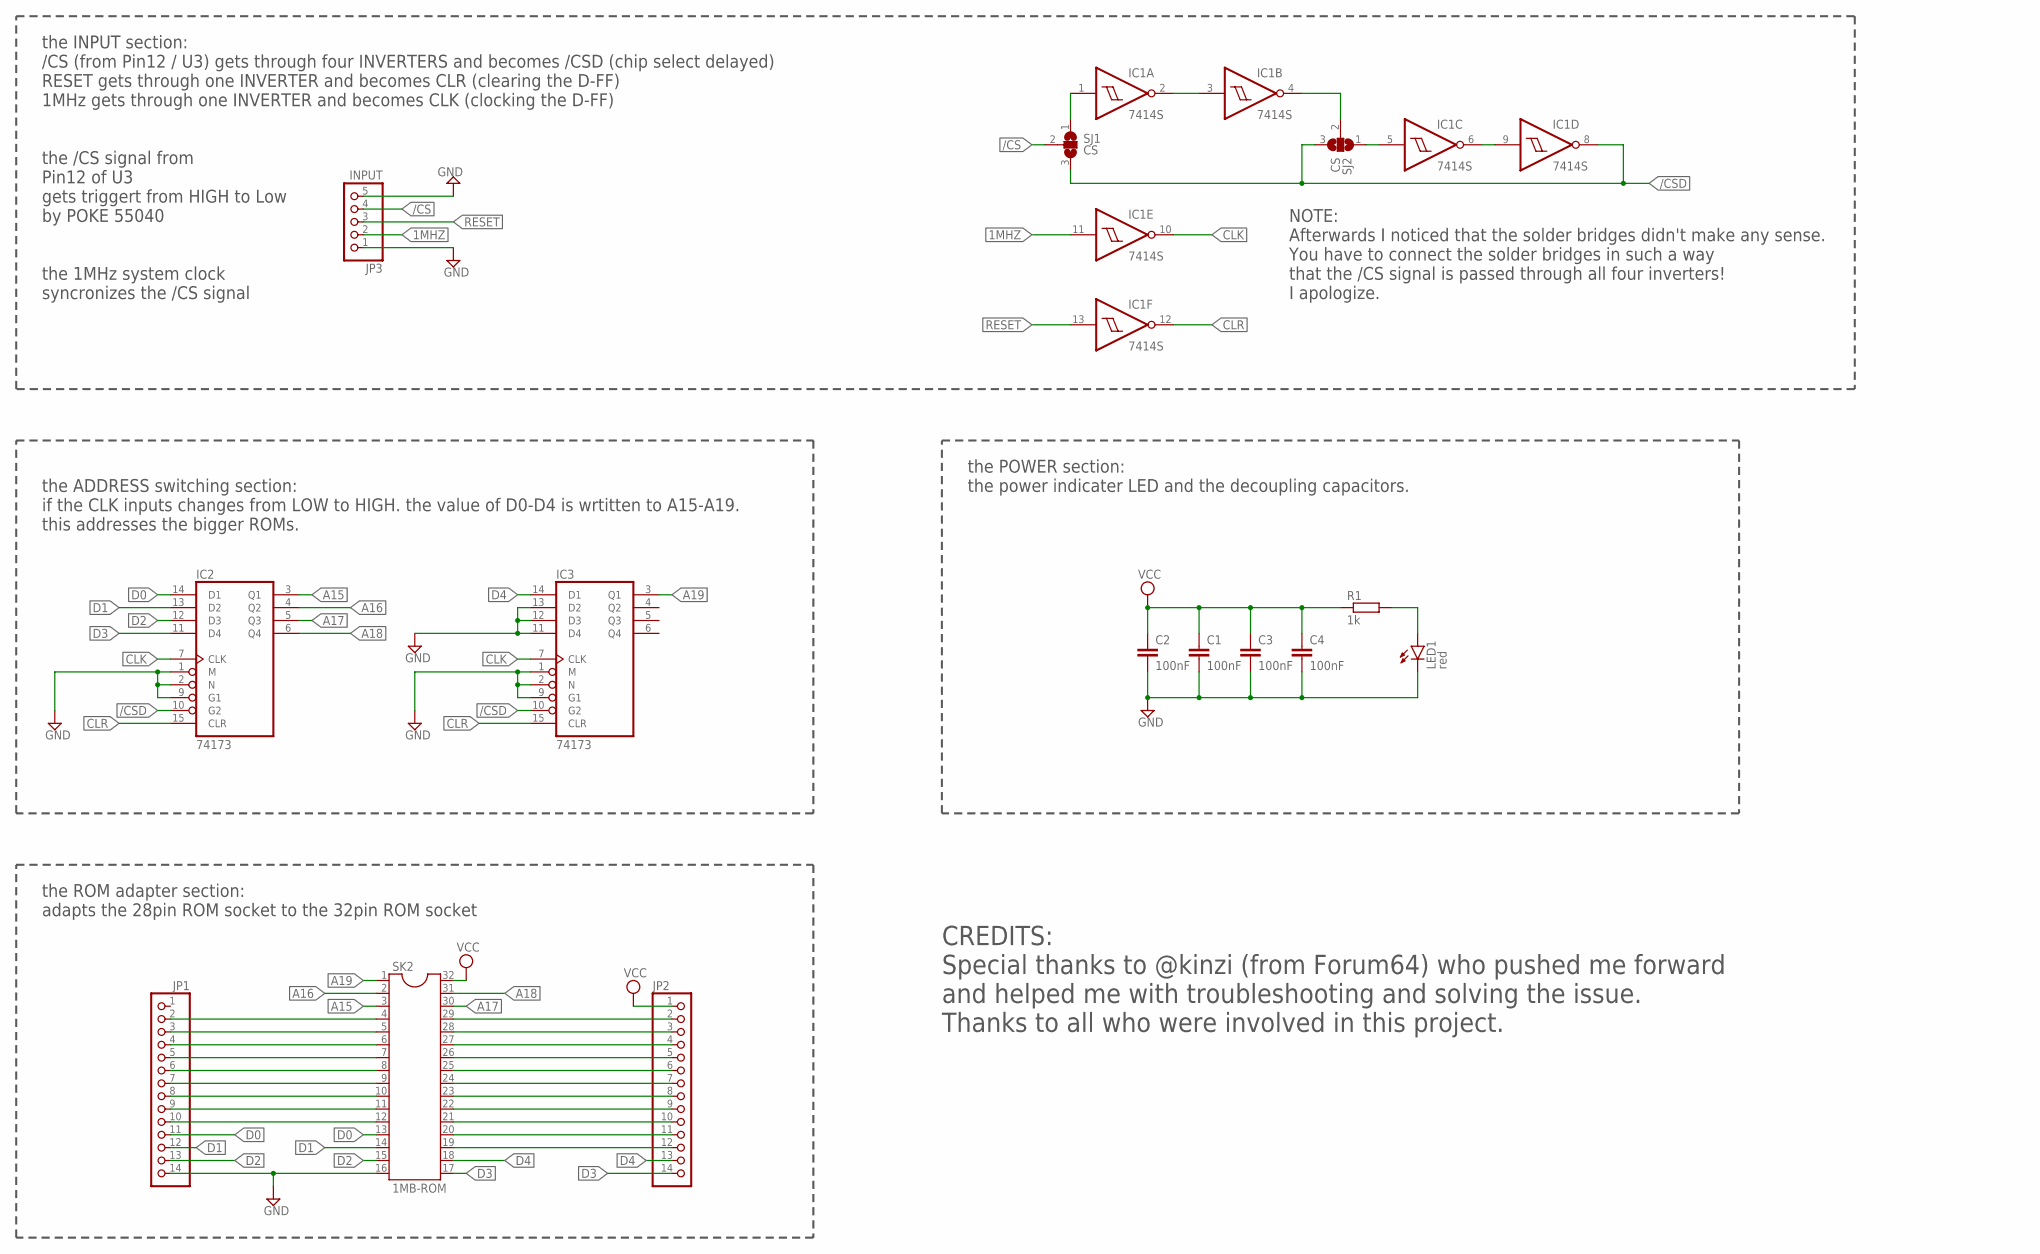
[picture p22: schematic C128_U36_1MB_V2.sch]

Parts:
C1, C2, C3, C4: 100nF; C0603K
IC1: 7414S; SO14_DET
IC2, IC3: 74173; SO16_DET
JP1, JP2: PINHD-1X14; 1X14
JP3: INPUT; 1X05/90
LED1: red; CHIPLED_0603
R1: 1k; R0603
SJ1, SJ2: CS; SJ_2
SK2: 1MB-ROM; DIL32

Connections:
1MHZ: IC1.11 (I), JP3.2
/CS: JP3.4, SJ1.2
/CSD: IC1.8 (O), IC2.10 (G2), IC3.10 (G2), SJ1.3, SJ2.3
A15: IC2.3 (Q1), SK2.3
A16: IC2.4 (Q2), SK2.2
A17: IC2.5 (Q3), SK2.30
A18: IC2.6 (Q4), SK2.31
A19: IC3.3 (Q1), SK2.1
CLK: IC1.10 (O), IC2.7 (CLK), IC3.7 (CLK)
CLR: IC1.12 (O), IC2.15 (CLR), IC3.15 (CLR)
D0: IC2.14 (D1), JP1.11, SK2.13
D1: IC2.13 (D2), JP1.12, SK2.14
D2: IC2.12 (D3), JP1.13, SK2.15
D3: IC2.11 (D4), JP2.14, SK2.17
D4: IC3.14 (D1), JP2.13, SK2.18
GND: C1.2, C2.2, C3.2, C4.2, IC1.7 (GND), IC2.1 (M), IC2.2 (N), IC2.8 (GND), IC2.9 (G1), IC3.1 (M), IC3.2 (N), IC3.8 (GND), IC3.9 (G1), IC3.11 (D4), IC3.12 (D3), IC3.13 (D2), JP1.14, JP3.1, JP3.5, LED1.C, SK2.16
unnamed: IC1.1 (I), SJ1.1
unnamed: IC1.2 (O), IC1.3 (I)
unnamed: IC1.4 (O), SJ2.2
unnamed: LED1.A, R1.2
unnamed: IC1.5 (I), SJ2.1
unnamed: IC1.6 (O), IC1.9 (I)
unnamed: JP1.2, SK2.4
unnamed: JP1.3, SK2.5
unnamed: JP1.4, SK2.6
unnamed: JP1.5, SK2.7
unnamed: JP1.6, SK2.8
unnamed: JP1.7, SK2.9
unnamed: JP1.8, SK2.10
unnamed: JP1.9, SK2.11
unnamed: JP2.2, SK2.29
unnamed: JP2.3, SK2.28
unnamed: JP2.4, SK2.27
unnamed: JP2.5, SK2.26
unnamed: JP2.6, SK2.25
unnamed: JP2.7, SK2.24
unnamed: JP2.8, SK2.23
unnamed: JP2.9, SK2.22
unnamed: JP2.10, SK2.21
unnamed: JP2.11, SK2.20
unnamed: JP2.12, SK2.19
unnamed: JP1.10, SK2.12
RESET: IC1.13 (I), JP3.3
VCC: C1.1, C2.1, C3.1, C4.1, IC1.14 (VCC), IC2.16 (VCC), IC3.16 (VCC), JP2.1, R1.1, SK2.32

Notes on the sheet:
the 1MHz system clock syncronizes the /CS signal
the /CS signal from Pin12 of U3 gets triggert from HIGH to Low by POKE 55040
the INPUT section: /CS (from Pin12 / U3) gets through four INVERTERS and becomes /CSD (chip select delayed) RESET gets through one INVERTER and becomes CLR (clearing the D-FF) 1MHz gets through one INVERTER and becomes CLK (clocking the D-FF)
the ROM adapter section: adapts the 28pin ROM socket to the 32pin ROM socket
the ADDRESS switching section: if the CLK inputs changes from LOW to HIGH. the value of D0-D4 is wrtitten to A15-A19. this addresses the bigger ROMs.
the POWER section: the power indicater LED and the decoupling capacitors.
CREDITS: Special thanks to @kinzi (from Forum64) who pushed me forward and helped me with troubleshooting and solving the issue. Thanks to all who were involved in this project.
NOTE: Afterwards I noticed that the solder bridges didn't make any sense. You have to connect the solder bridges in such a way that the /CS signal is passed through all four inverters! I apologize.

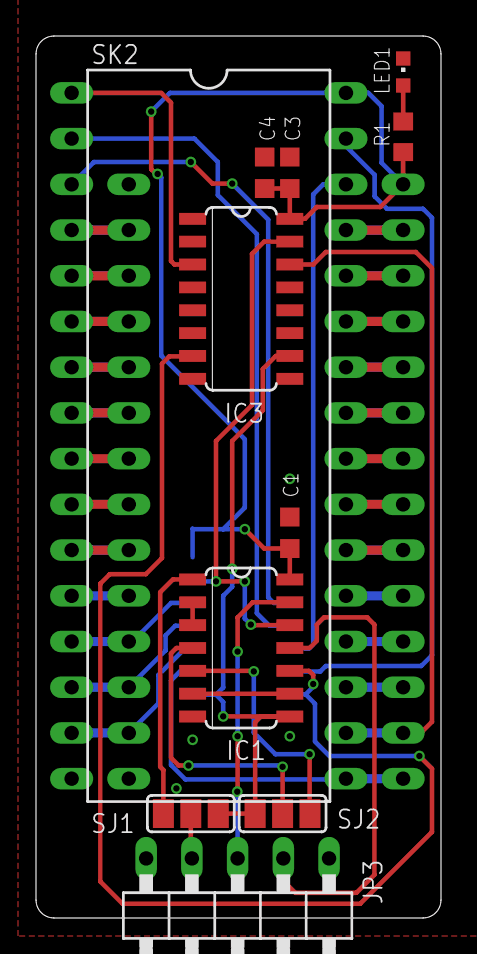
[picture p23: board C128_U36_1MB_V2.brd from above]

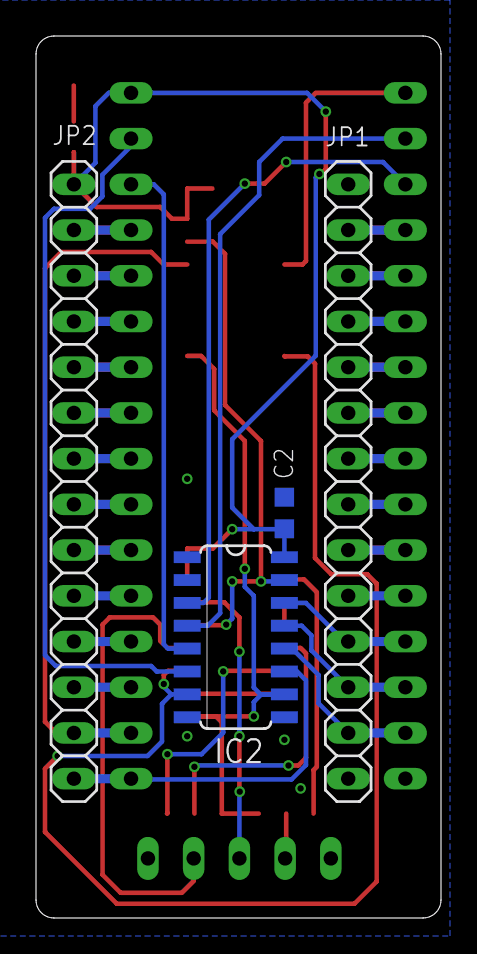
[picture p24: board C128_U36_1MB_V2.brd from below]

Board: 2 copper layers, 22.5 x 49.0 mm, 15 parts (4 on the bottom side), 44 nets.
